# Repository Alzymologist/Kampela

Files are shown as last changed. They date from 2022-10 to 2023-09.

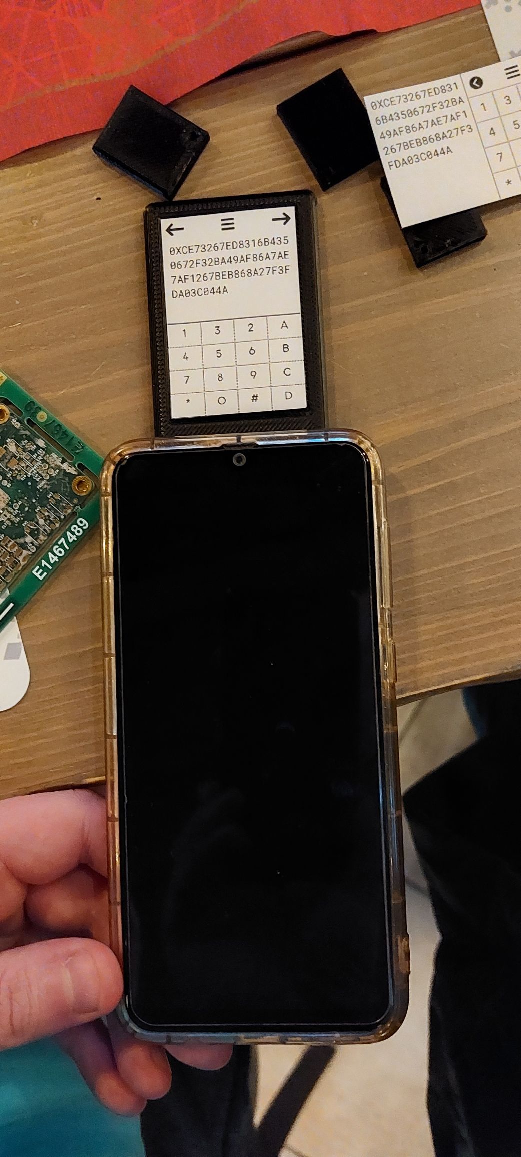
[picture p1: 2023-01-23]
hardware/development/Kampela_C1_enclosure/dummy/20230111_154535.jpg

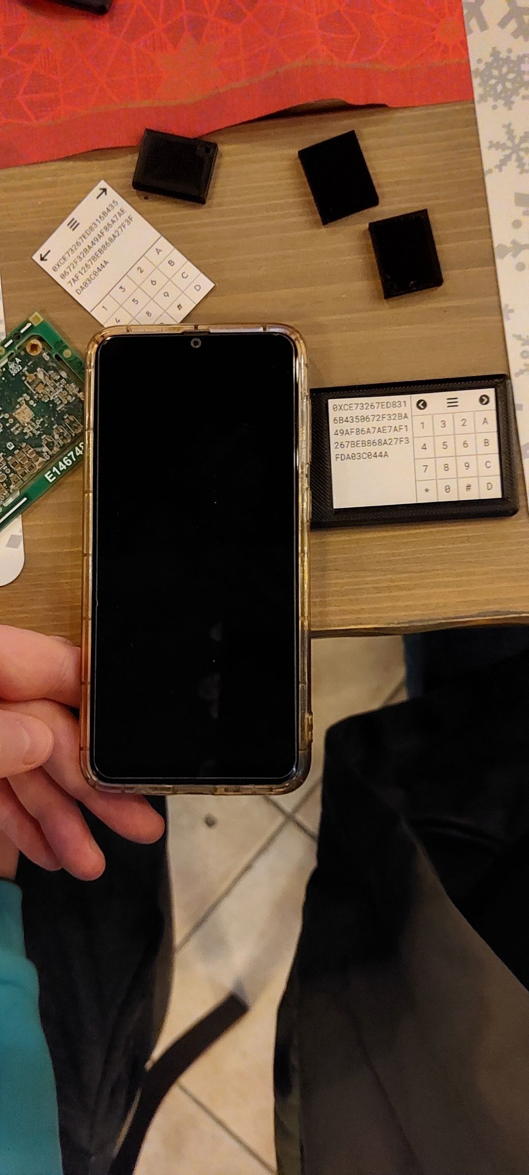
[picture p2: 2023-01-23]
hardware/development/Kampela_C1_enclosure/dummy/20230111_154515.jpg

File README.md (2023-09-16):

# Kampela
Hardware signer and key storage for Substrate ecosystem.
https://kampe.la

-------------------------------------------------
As of September 2023, this monorepo became really hard to work with, and had been splitted into multiple ones under the new [Kalapaja](https://github.com/Kalapaja) organisation.  
⚠️ This repo is kept up for archival reasons, please submit any issues and pull requests in that new org instead.

The new repository structure under Kalapaja is the following:

| New repository | Original subfolder | Description |
|---|---|---|
|[kampela-firmware](https://github.com/Kalapaja/kampela-firmware)|[`firmware/development`](https://github.com/Alzymologist/Kampela/tree/main/firmware/development)|Firmware sources and associated software projects|
|[kampela-hardware](https://github.com/Kalapaja/kampela-hardware)|['hardware/development'](https://github.com/Alzymologist/Kampela/tree/main/hardware/development)|Hardware design schematics and supplementary files|
|[kampela-common](https://github.com/Kalapaja/kampela-common)|['common'](https://github.com/Alzymologist/Kampela/tree/main/common)|Collection of shared libraries used by both "hot" and "cold" side of the project|
|[siltti](https://github.com/Kalapaja/siltti)|[application](https://github.com/Alzymologist/Kampela/tree/main/application)|Android companion app to interface with the device|
|[docs](https://github.com/Kalapaja/docs)|[docs/development](https://github.com/Alzymologist/Kampela/tree/main/docs/development)|Miscellaneous docs documenting different aspects of the project|

-------------------------------------------------

## Project summary
Kampela is a hardware version of Parity Signer. It is a small card-shaped device (ideally comparable to a credit card form factor, to be carried in a wallet when needed) that accepts data through unidirectional NFC port and shows output on a monochrome electronic paper screen. It has cryptographic strongbox with elliptic curves supported by Substrate —  which only stores private keys (after initial import) and performs all signing operations on-chip.

Kampela is designed to be a comparatively low-cost (below €100, in contrast to €500+ for a Signer-compatible smartphone) single-purpose device, which would only support a single seed phrase per unit, operated via a drastically simplified user interface. However, it would have all the security features of Parity Signer: a full-featured SURI account derivation system, transactions preview, metadata updates, logging.

As something that supports the same QR code output formats as Signer, it would be able to drop-in replace Signer when providing signatures back to a mobile/desktop wallet. The only challenge would be in transforming the current QR-driven input format of Signer into a suitable NFC payload. Alongside with native support in some apps (which would require software modification) this can also be achieved with a tiny “translator” app for a regular (online, not necessary trusted — one’s usual daily driver) mobile phone: it would snap a QR code with the transaction details and (statelessly, without any extra features or complicated UI) transform that into an NFC payload.

Kampela is a natural (and long-discussed) extension of Parity Signer to leverage the most out of modern hardware-based crypto chips and drastically reduce Signer’s attack surface: no mobile OS, not extra platform features, no unexpected communication methods or airplane mode to take care of.

Kampela is not a wallet! It is a signing tool, it is not able to track on-chain balances, validate things over chain-provided information or generate transactions on itself.

## Problem statement

Parity Signer project is a unique solution to provide user-friendly secure airgapped signing with seamless integration into ecosystem. However, there are certain problems that could not be solved at the moment:

Hardware cryptographic chips in modern phones do not support elliptic curve algorithms used in Substrate networks — so in result secrets being exposed to the main RAM of the device for the duration of usage (only hardware-encrypted at rest), where it may potentially leak or be accessed by malicious software.

Current hardware compatibility is limited: only newer iOS devices and few latest models of Android devices support hardware encryption of secrets. This puts supported devices on the more expensive side of the price range.

With iPod Touch being decommissioned, all devices currently in production which support necessary hardware features also include baseband chip — which runs a separate closed-source OS running on a separate, special-purpose chip while commonly having a full DMA access to the main phone’s memory. This chip could not be trusted (see Samsung’s baseband backdoor as an example) and has potential to leak secrets through radio channel or by use of kleptography, overriding on-board entropy generation or execution environment.

## Details

Kampela is an approximately credit card sized box with a rectangular screen and minimalistic controls (capacitive buttons alongside the screen or something similar — to be designed). In addition to development of the device itself (which will be available under suitable FOSS licenses both in terms of software and hardware designs), a reference MVP implementation of QR-to-NFC converter app will also be created.

After seed phrase initialization (either input or random generation — the latter being a potential technical challenge due to its computational/UX intensity and lack of entropy available) it will be stored in an hardware-backed encrypted storage. Address derivations could be created in Kampela either by passing derivation strings from mobile device via NFC (since those are not secret on their own) or by typing on the device itself (with some form of dictionary-driven assisted input, due to limited controls available); resulting public keys could be exported through QR codes, in the exactly the same way as with Parity Signer. Transactions for signing are sent into Kampela via NFC, their contents rendered on low-power e-ink monochrome screen and then user can unlock the device and sign transaction. Unidirectional nature and limited range/direction of both communication interfaces ensures that user remains in full control of data. Kampela has no battery (at least no battery for long-term power supply) and is powered only through NFC — which adds another layer of security, since no long-term backdoors can survive in RAM, and compromising the stored firmware itself is a much higher bar to clear for the attackers. Kampela will use a Secure Element or similar technology (like Arm TrustZone) to store secrets in a way, which will make it as hard as realistically possible to extract the secret keys, even with full physical access to the device and lab equipment being available.

Kampela is envisioned to be as close to open hardware criteria as possible, as long as it won’t compromise the resulting security model directly (for example, if requirement to support arbitrary user-provided firmware would clash with chosen security model, we would choose security model; all such cases would be clearly argumented and documented, of course). All security-sensitive parts of the device (NFC, RNG) would be implemented as much as possible through discrete, fixed-logic components (potentially with FPGA for the more uncommon parts of it, like sr25519  crypto) instead of being done “in software” or trusted to all-in-one integrated chip developers. Firmware for the programmable part of the device is to be written in Rust. On the smartphone companion app, it would use the same proven combination of Rust and native platform-dependent frameworks as Parity Signer currently does.

Unlike other projects in the similar problem space (which routinely withheld certain design specifications, and make others only available under an NDA, see, for example, discontinued project Cobo), we aim to make an extreme push to transparency of our designs, both on hardware and software layers. While this is expected to provide a boost in security and verifiability of Kampela devices, this severely restricts any potential future commercialization effort, since the competition (which wouldn't have to recover R&D costs) would undercut any official manufacturers on profit margins. We'd prefer this extreme competition to be a feature, not a bug; the only project with comparable manufacturing model would be Trezor, but it has a series of well-known shortcomings both in design and hardware choice areas.

## Ecosystem Fit

Currently, there are not too many options to securely handle keys in the Polkadot/Kusama ecosystem. There’s some Ledger support (which is often lagging behind the runtimes update cadence, and doesn’t exist for all the parachains out of the box), and Parity Signer and it’s fork Stylo (which requires an expensive smartphone device being used for this airgapped purpose only, and also has a much wider attack surface due to the device having a general-purpose OS and at least potential WiFi/3G/Bluetooth connectivity). We expect Kampela (having its own set of quite distinct tradeoffs) to supplement those two solutions — and integrate nicely with other layers of the tech stack (wallets, browser extensions etc), being a drop-in replacement of the currently already broadely supported Parity Signer.

## Origins of the name

Kampela, a flatfish — since the device is flat and is intended to resist phishing.

## Why Polkadot network?

Kampela project is a long-missing component to ultimately harden security of the whole Substrate ecosystem and ensure it’s secure and unstoppable status in long-term. Polkadot part of the greater ecosystem, as flagship and stable reference core, is natural space to develop universal solid solution like Kampela.

## Reviewers responses

Q: I think the NFC part isn’t very great from a usability perspective.

A: On contrary, NFC transfer of data into the device would be much smoother than with QR movies, especially for large payloads like metadata. The idea is that user will attach Kampela to the back of the smartphone, perform all the operations that do not require security with convenience of familiar smartphone interfaces, then flip the stack over and perform secure operations until output QR is shown. With QR presented on e-ink screen, Kampela could safely be detached from the phone as the QR intended for public broadcast would remain on screen. The task of mechanical engineer in this project (in addition to making device casing cheap to produce and robust) would be to ensure this flow is as comfortable and universal across the phones as possible.

Q: I guess the user does not really care about the RAM exposure as long as my phone is offline all the time.

A: Unfortunately, this is not so. The applications that could corrupt memory used by the signing application could manipulate RNG into leaking arbitrary data (including leaked secrets) through kleptography methods without exposing the leakage in any way. The leaked secrets could be broadcasted secretly through signature screen or other non-disabled communication methods via steganography. Finally, secrets leaked to memory could be stored outside of hardware encrypted storage negating its benefits in case attacker has physical access to the device reducing his need for fully-equipped forensic lab to relatively cheap and widespread memory dumping equipment. The Kampela solves these issues by lack of shared execution environment (and potentially rogue independent blackbox systems on board) and solid rust code with proper zeroization implemented.

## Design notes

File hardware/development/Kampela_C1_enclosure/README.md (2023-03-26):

## Mechanical design

The Kampela enclosure must meet many requirements:
1. Transparent design - the user must, among other things, visually understand that his Kampela has an original open-source design, manufactured at an authorized factory without any visible modifications.
2. Resistance to physical hacking and modification - access to the modification of electronics and flashing not factory firmware should be as difficult as possible.
3. Resistance to accidental breakage, abrasion, and display breaking - the basic requirements for carrying a device in your backpack
4. Fixation on the phone during use - the possibility of convenient simultaneous work of the user with a smartphone and with the Kampela touch screen both on hands and in a fixed position on the table.
5. Consisting of 2 parts - Kampela itself and an additional NFC key in the form of a keychain inserted into the middle part of the Kampela antenna.
6. Large touchscreen display to allow simultaneous viewing of keys and entry of verification codes on a randomized touch keyboard.

Based on the requirements and research results, we decided to manufacture the Kampela enclosure in the form of casting the board and display using Low-Pressure Molding technology into transparent amber polyimide.
This technology offers good opportunities for Kampela:
- Low-Pressure Molding, unlike two-component molding and injection molding, allows electronics to be technologically molded without damage from pressure or temperature.
- Polyimide is transparent, you can make sure that the copy of Kampela has the original design and corresponds to the open-source documentation.
- With the correct technology, polyimide is almost impossible to separate from the board without visible traces, thus hidden modification of electronics is excluded.
- The material, after curing, has a hardness of 80 Shore A. In combination with the semi-gloss surface texture, Kampela will adhere well to a smartphone. This will make it easy to work with Kampela when using both on the go and the table.
- Low-Pressure Molding allows you to make the device completely sealed and shock-absorbing when dropped, making Kampela resistant to accidental breakage.

## How to make your prototype Amber Kampela

For the Kampela prototype, we prepared 3D models so that any enthusiast can repeat Kampela and test usability.
Low-Pressure Molding equipment is not available to everyone, but the technology of two-component molding of polyurethane into silicone molds allows you to repeat the concept of Kampela molding in almost any workshop.
The algorithm for pouring two-component polyurethane is as follows:
0. You should have a Kampela board assembled, sewn, and fully tested, a set of transparent molded silicone with a silicone mold hardener, a kit of molded two-component polyurethane for molding (amber, 80 Shore A), corrugated cardboard for mold walls, hot glue gun for sealing joints when pouring silicone, release wax spray, sharp scalpel for parting a mold, SLA 3D printer for printing a master model for pouring, dirty room or polyethylene-covered floor and workplace (be careful! Two-component casting components are very difficult to remove from furniture, floors, and clothes, so it’s better to immediately tighten everything with disposable plastic wrap)
1. Print the master model on the SLA 3D printer using the STL file from the GitHub repository
2. Make a silicone mold box out of cardboard by adding a minimum of 3cm on each side of the master model. Be sure to seal the joint between the bottom and the walls of the box with a heat gun for pouring, otherwise, the silicone will leak into the joint, as it is very fluid.
3. Glue the master model to the bottom of the box with the Kampela screen facing up using thin double-sided tape so that it does not float when poured.
4. Spray the wax release agent onto the master model from above.
5. Mix and pour the casting silicone according to the instructions on it up to half the box, but so that the master model is completely covered with silicone. Wait for the silicone to cure
6. After curing, remove the pot from the box, turn it over and insert it into the box with the visible master pattern facing up. Do not remove the master model. Glue 2 wooden sticks or tubes from soda with a diameter of 4-6 mm to the master model on both sides of the mold to then pour polyurethane through them - one for pouring, the second for the air outlet. Spray the wax separator over the top. Fill the second half of the mold with silicone. Wait for confirmation.
7. After the mold has cured, you can split the mold, remove the master model, clean the mold with a brush or compressor from dirt and start casting polyurethane.
8. To fill the mold with polyurethane, assemble the injection mold: place the assembled Kampela board with the display, and position it on the buttons and silicone ledges in the master model. Close the mold and fasten sheets of hard cardboard at the top and bottom and fasten the mold with rubber bands so that it is tightly assembled, but the sprues are accessible for pouring with a syringe.
9. Mix polyurethane according to the instructions for it, and degas according to the instructions. Then, with a large disposable syringe of suitable capacity, without a needle, suck the polyurethane from the mixing container and pump it into the silicone mold until enough polyurethane comes out of the air hole. Make sure that the form lies on a plane horizontally so that the polyurethane does not flow out and there is no possibility of the formation of bubbles in the voids of the form that will be above the air outlet channel.
10. Once the polyurethane has cured, you can use your sealed and shockproof Kampela.

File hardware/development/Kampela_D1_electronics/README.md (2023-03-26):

# D1 iteration electronics design progress:

## Display and touchscreen

For ease of use with the device, this iteration used a 2.7" e-inc touchscreen display. We also examined e-inc displays of other diagonals in terms of usability and usability in the Kampela layout, as well as displays powered by memory technology displays. Alternative display manufacturers with the same parameters were also found to ensure supply reliability.

Displays based on memory display technology look very promising - the refresh rate compared to e-inc allows for a more responsive touch interface. The problem lies in the small number of manufacturers of suitable displays found and the lack of available touch screens for such displays. Security aspects of using this technology should also be carefully analyzed, as sensitive key material does indeed pass through memory display’s memory cells, which have some limited non-volatility. Yet in the future iterations, we want to work more with memory display and try to implement a fast, responsive touch interface, possibly with color.

## Separate layout of the coil and main board

In this iteration, the NFC coil has been separated from the main board. This was done based on the following tasks:

1. When placing the board with the display and the coil in the case, taking into account the thickness of the display, the protection of the display, and the case, it turns out that the coil moves away from the phone at a distance of more than 3mm, which negatively affects the efficiency of wireless power transmission and the overall power reserve in Kampela. The division of the coil and the main board into 2 boards in this case allows you to place the coil in the case as close as possible to the plane of the smartphone while using the device remains just as convenient.

2. The separate layout of the coil and the main board allows you to experiment with different coils in the package without changing the main board. In the next iteration, we will be able to choose the optimal coil option in this way.

## Self-destruct mechanism

In latest iteration, device self-destruct chains were added, activated by the user either by physically damaging the screen or other area of casing and then exposing Kampela to NFC field; we would experiment to determine most reliable and convenient method in the next milestones. Self-destruct indication circuits have also been added so that the user can visually check that the device cannot be used for its intended purpose after self-destruction: instead of RED power overload LED, a BLUE LED indicating successful processor wipe would be illuminated.

## Separation of display and touch screen resets

In the first prototype, lots of cross-talk was found between display and touch panel circuits: power dip on screen refresh occasionally triggers touch touch events, i2c line gets locked, etc. Thus the RESET circuits of the display and the touch screen were separated due to mutual influence during operation. The power circuits of the display and the touch screen were also separated and optimized to avoid their negative influence on each other. Furthermore, this would improve power management of Kampela, as with this separation touch panel could be disabled during screen update, significantly reducing power drain and subsequently brown-out probability during normal operation.

## Improvements to component patterns and board layout

In this iteration, the documentation for the display, touchscreen, cables, and other components has been clarified, and the component patterns have been corrected and optimized. The layout of the board has also been optimized so that the cables take a mechanically unstressed position, and the mounting of components on the board has also been optimized.

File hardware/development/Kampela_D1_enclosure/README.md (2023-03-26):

# D1 iteration mechanical design progress:

## Aluminum body frame

In the process of working on the flooded version of Kampela, the lack of strength of the flooded device was revealed - both in terms of the integrity of the board and in terms of the integrity of the display. Also, in the process of working on the molding of the board with the display, problems with stable and accurate positioning of the display during molding were identified. To avoid these problems, it was decided to add a rigid frame to the layout, which would increase the rigidity of the structure and would allow the elements to be reliably positioned when pouring the compound. Aluminum was chosen as the frame material for the time being, and non-conductive, lighter and more corrosion-resistant plastic materials are considered in future. The influence of metal on the efficiency of wireless power transmission was experimentally investigated and measures were taken to increase efficiency - slots were added to avoid closed turns.

## Active NFC dummy tag inlay

As an additional authentication factor, as well as for direct communication between the NFC smartphone and Kampela, we use an NFC memory chip with an independent antenna. It was decided to implement this scheme in the form of a hermetic key fob detachable from the main device, without which Kampela does not allow to perform its functions. The key fob is implemented in the form of a small printed circuit board poured into a transparent compound and placed inside the main Kampela coil. Structurally, the key fob is implemented in such a way that it does not fall out of the case when using Kampela directly with a smartphone, but if necessary, it is possible to remove it from the Kampela case for inspection that the circuits are indeed indepentent, and, if we manage to implement proper strong signing in active tag, use the fob as second authorization factor. At the moment, the most optimal design of the tag was chosen with a transparent plastic base, a printed circuit board of the tag embedded in it, and the subsequent hermetic filling of the tag.

## Filling and sealing

Experiments with sealed PCB potting showed good technology potential for the device, but also revealed several technical problems:

- When pouring, accurate and reliable positioning of the display and printed circuit boards are required, otherwise, they may "float" in the volume of the poured compound and change their final position.

- Some fill elements are very thin, such as the protective damper around the display and the area around the display and touch screen flex cables. The small thickness makes it difficult to pour without bubbles and cavities at low filling pressures. The use of high pressures for filling electronics and e-inc displays is not possible

- Flexible cables of the display and touch-screen require fixing before pouring in order not to go to the pouring surface and form air pockets.

Based on these issues, it was decided to use a rigid aluminum frame to solve these problems, and to perform a hermetic filling from the back of the device. At the same time, the device remains transparent and sealed and does not allow hidden modifications. In the next milestones, we will work on optimizing the layout and design of Kampela to make it more technologically advanced and more user-friendly.

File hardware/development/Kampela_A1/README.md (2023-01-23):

# CoilDisp

This devboard uses `STN32L432KCU` mc to test power harvesting to power a e-ink screen.

## Power harvest

The board supports connection of printed coil or external coil. Additionally, a UFL connector for VNA for coil model parameters analysis is implemented

## Power storage

The power is stored in smd ceramic capacitors; external connections for electrolytic capacitors to support londer unpowered states and balance high poewr consumption during screen refresh cycle are implemented

## Screen

The component for testing is PervasiveDisplays model E2154CS0C1

[Datasheet](https://www.pervasivedisplays.com/wp-content/uploads/2021/12/1P255-00_03_E2154CS0C1_202111203doc.pdf) and [programming guide](https://docs.pervasivedisplays.com/epd-usage/epd-driving-sequence/small-epds) are available at PervasiveDisplays website.

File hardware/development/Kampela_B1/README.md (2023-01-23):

# Kampela conveptual testing module

This PCB tests several important concepts that would be used in actual Kampela device.

## Signal forming circuit

Filter stage is added on data input channel to intercept smartphone data and active NFC tag responses.

## Touchpad

Connector for touchpad is added to this board.

## Overdrive indicator

Excess power is dissipated through a clamp with LED. Brightly shining this LED effectively indicates that signal power is more than enough and could be used for Kampela alignment.

## RAM

RAM chip is added to the board to check its performance with our power system.

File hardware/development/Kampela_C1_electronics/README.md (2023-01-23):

# Kampela integration prototype

This is the design for the first version of complete Kampela device.

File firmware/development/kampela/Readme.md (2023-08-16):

# Requirements
We assume that you have linux.

Set of packages as well as commands could vary depending on your distribution.
Following is valid for ArchLinux.

Install rustup and ARM toolchain:
```sh
[sudo] pacman -S rustup arm-none-eabi-gcc arm-none-eabi-binutils
rustup update
rustup default stable
```

Also you will need a program for flashing.

For Pilkki flasher look [here](https://github.com/Alzymologist/pilkki).

For Segger you need to install [simplicity-commander](https://www.silabs.com/developers/mcu-programming-options).
In case of ArchLinux there is [AUR package](https://aur.archlinux.org/packages/simplicity-commander).

# Preparations

```sh
rustup target add thumbv8m.main-none-eabihf
cargo install flip-link
```

# Build

```sh
cargo build --release
```

## Flashing

In case of Pilkki:
```sh
./binarize.sh --pilkki
```

And in case of Segger
```sh
./binarize.sh --segger
```

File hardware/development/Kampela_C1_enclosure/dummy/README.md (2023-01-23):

# Casing design development

This folder contains casing design dummies information. These were intended to be 3-d printed to get a feel of Kampela in use with typical smatrphones.

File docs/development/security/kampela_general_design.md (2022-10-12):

# Kampela screens

Kampela has two screens:

- QR screen (for QR exports and signatures)

- Display screen (for other data: derivations list, specs available, verifiers etc)

All output from Kampela must be through either of these screens.

# Kampela gets commands only through interface

By receiving appropriate NFC from introduced device, Kampela can:

- load chain specs (save specs in storage)
- create an address (save public address information in storage, create export QR on Qr screen.)
- sign a transaction
- sign a text message
- remove chain specs
- remove an address
- show info in Kampela (nothing is sent, Kampela own controls are used)

NFCs from alien devices are not accepted. Introducing device requires pin code.
Any action on Kampela requires on-Kampela user confirmation (i.e. user reading from Kampela screen the incoming transaction) and a pin entry.

# Kampela is as expected

There must be a set of checks for Kampela in place.

1. Code/design are audited, well, at least looked into, as any open source.
2. Factory receives chips as designed.
3. Assembly in factory is as designed.
4. Firmware in factory is as designed.
5. Assembly/hardware remains the same while in transit to user.
6. Firmware same remains the same while in transit to user.
7. Assembly/hardware can not be swapped quickly and discreetly while Kampela is with user.
8. Firmware can not be swapped quickly and discreetly while Kampela is with user.

# Summary of secret-related storage in Kampela.

1. Part of chip own secret key, as set in chip factory.
2. Part of chip own secret key, added in Kampela assembly factory.
As the Kampela exits the Kampela assembly factory, the chip secret key is complete, and factory records the Kampela public key.
User checks that the chip is genuine by signing a challenge with chip secret key and verifying with public key known at Kampela factory.
3. Firmware build is stable. Its hash must match the officially published one. Hash is checked, ledger-like protocol here.
4. User own secret (seed phrase, secret key?) - entered by user, stored encrypted with chip-intrinsic PUF-containing key (same as 2 or separate?).
5. Pin code - for unlocking the Kampela; possibly mix into user secret encrypting key (4).
6. Companion phone(s) public key(s).

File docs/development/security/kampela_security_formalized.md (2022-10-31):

Kampela protects only user secrets, user assets, and user identity.
This text deals only with the effects of various attacks on user.
Attacks are ranged by proximity of the potential attacker to Kampela device.

Integrity breaches are considered entirely unacceptable. Base incentive: High.
Confidentiality breaches are highly undesirable. Base incentive: Medium.
Availability breaches could be tolerated. Base incentive: Low.

Note: availability failures might be used as basis for blackmailing attack though, where, even though the secrets are safe (considering that user did indeed follow backup protocol), financial damage could occur. Think big brute holding your device and demanding a dollar to give it back; for a small enough sum, this transaction might happen regardless of whether Kampela is still operational or even actually returned upon payment. This is not very different from similar attacks elsewhere and would not be considered here much, as only user's wits could protect from these.

There is one special case, where the user is tricked into using account with derivation path known only to attacker; here the legal user and an attacker share components to unlocking the account and would have to negotiate. Here, though, the secret is actually compromized in one signature or public key generation event; thus technically this is an integrity breach (much like signing a single malicious proxy call to delegate full control to attacker). Attacks where public key is substituted outside of Kampela are out of scope here.

# 1 Kampela in direct access, for unlimited period of time (stolen, found, etc)

Note 1. If an attacker knows the pin code, the game is over, it is the same as if the attacker has the secret phrase. We will assume that the attacker does not have the pin.

Note 2. User must follow end-of-life disposal protocol, otherwise normal use will end up here.

Base effort: Medium

## Confidentiality

Motivation: Stalk or expose the user.

1-C1

Attacker action: Get all public keys, including the ones the user hides from wide public, stalk user through polkascan.

Effort: Medium

Incentive: Medium

## Integrity

Motivation: Get access to user identities and assets.

1-I1

Attacker action: Read secret phrase. Attacker must break through authentification.

Effort: High

Incentive: High

1-I2

Attacker action: Carefully disassemble the device, read secret with advanced instrumentation.

Effort: High

Incentive: High

1-I3

Attacker action: Proxy account control. Attacker must break through authentification.

Effort: High

Incentive: High

1-I4

Attacker action: Attacker takes the device after it is unlocked by user.

Effort: High

Incentive: High

## Availability

Note. If user loses whether the detachable token, or Kampela, or both, the availability is inevitably lost.

# 2 Kampela in direct access, briefly (stolen and returned, device remains the same)

Note. If attacker knows the pin code, the game is over, attacker same as has the secret phrase. Assume here they don't have the pin.

Base effort: Medium

## Confidentiality

2-C1

Same as direct access for unlimited period of time.

## Integrity

2-I1

Motivation: Get the secret phrase.

Attacker action: Break pincode by observing physical state of the Kampela (scratched buttons, etc).

Effort: High

Incentive: High

2-I2

Motivation: Swap chain specs so that later transactions are parsed incorrectly and signed without knowing true content.

Attacker action: Send chain specs NFC payload, accept it.

Effort: High

Incentive: Medium

2-I3

Motivation: Swap chain verifier so that later compromised metadata is fed to Kampela, thus transactions are parsed incorrectly and signed without knowing true content.

Attacker action: Send chain specs NFC payload with new verifier, accept it.

Effort: High

Incentive: Medium

2-I4

Motivation: Seed phrase swap.

Attacker action: Change seed phrase, user generates wrong public key in companion and uses it to accept assets. Attacker must break through authentification.

Effort: High

Incentive: High

2-I5

Motivation: Seed phrase swap.

Attacker action: Coerce user to remove secret. Enter wrong secret (by taking Kampela shortly). User then generates wrong public key in companion and uses it to accept assets.

Effort: High

Incentive: High

2-I6

Motivation: Maliciously re-programm Kampela.

Attacker action: Kampela is shortly taken from user, re-programmed (for example, to compromize the secret through defective randomness), returned to user.

Effort: High

Incentive: High

## Availability

2-A1

Motivation: Destroy or block device.

Attacker action: Physically break device or enter wrong pin multiple times.

Effort: Medium

Incentive: Low

2-A2

Motivation: Temporarily stagger user activity.

Attacker action: Delete or damage seed.

Effort: Medium

Incentive: Low

2-A3

Motivation: Temporarily stagger user activity.

Attacker action: Remove one or more user addresses manually.

Effort: Medium

Incentive: Low

2-A4

Motivation: Temporarily stagger user activity.

Attacker action: Remove one or more chain specs manually.

Effort: Medium

Incentive: Low

2-A5

Motivation: Block user assets.

Attacker action: Copy derivation path, remove address manually, if user does not have backup, assets on address are blocked.

Effort: Medium

Incentive: Medium

# 3 Kampela in close proximity (watched over shoulder)

Base effort: Low

## Confidentiality

3-C1

Motivation: Peek at user's transaction.

Attacker action: Look over the shoulder or tap NFC field, it would probably be visible on other devices as well.

Effort: Low

Incentive: Low

3-C2

Motivation: Learn user's public key.

Attacker action: Look over the shoulder, it will be shown on other devices as well.

Effort: Low

Incentive: Low

## Integrity

3-I1

Motivation: Observe pin code or password.

Attacker action: Look over the shoulder, listen to button sounds.

Effort: Medium

Incentive: High (requires access to device later)

3-I2

Motivation: Make user sign malicious transaction.

Attacker action: Send transaction through powerful enough NFT transponder (and hope that user does not read it attentively).

Effort: High

Incentive: High

3-I3

Motivation: Swap chain specs so that later transactions are parsed incorrectly and signed without knowing true content.

Attacker action: Send corrupt chain specs with powerful transponder, make user accept them.

Effort: High

Incentive: Medium

3-I4

Motivation: Get information (possibly secret one) from device.

Attacker action: Listen to electromagnetic noise from device.

Effort: High

Incentive: High

Note. Research needed. Emissions should be minimal.

## Availability

3-A1

Motivation: Break device from a distance

Attacker action: EMP.

Effort: Medium

Incentive: Low

Note. Breaking may be unintentional, for example, burning circuits with too high signal (supermarket anti-theft etc).

# 4 Kampela far away (attacks without breaking the companion app)

Base effort: None

## Confidentiality

## Integrity

4-I1

Motivation: Trick user into signing proxy account.

Attacker action: Send proxy call, use social engineering.

Effort: High

Incentive: High

4-I2

Motivation: Trick user into switching to malicious verifier.

Attacker action: Use social engineering to make user change verifier.

Effort: Medium

Incentive: Medium

4-I3

Motivation: Distribute malicious chain data.

Attacker action: Steal verifier key or be malicious verifier.

Effort: High

Incentive: High (could be scaled to many users)

4-I4

Motivation: Trick user into signing transaction blindly.

Attacker action: Use social engineering.

Effort: High

Incentive: High

4-I5

Motivation: Use message signing to make signature usable elsewhere.

Attacker action: Find vulnerability where "sign message" mechanism has insufficient replay protection or message that collides with call, make user sign it.

Effort: High

Incentive: Medium

4-I6

Motivation: Compromise device firmware during an update, expose data and assets.

Attacker action: Publish/propose Kampela update that would install damaged/incorrect firmware into Kampela. User may sign transactions they did not agree to, or create addresses they did not wish to. Attacks may occur only if certain conditions are met, and thus be difficult to detect.

Effort: High

Incentive: High

4-I7

Motivation: Make user sign a wrong message.

Attacker action: Compose "sign_message" content with utf-8 symbols that are not printable and/or are metasymbols (reverse text direction, move caret, etc.), so user reads and signs different messages.

Effort: Medium

Incentive: Low

4-I8

Motivation: discover user pin code (device is later stolen to use the pincode and retrieve the secret).

Attacker action: Kampela, when used, is close to the companion device, maybe attached, definitely in visible proximity. Compromized companion device may record pictures of user entering pin code, analyze sensor data or button sounds to deduce what buttons user is pressing when entering the pin code.

Effort: Medium

Incentive: High

## Availability

4-A1

Motivation: Trick user to break device.

Attacker action: Convince user that blocking actions should be performed (self-destruct mechanism, verifier recall, EMP).

Effort: Low

Incentive: Low

# 5 Swap used Kampela (original device is replaced after secret entering)

Base effort: Medium

This includes only attacks through swap itself. Attacks through taken Kampela are discussed above, in 1-2.

User may not notice that the secret is missing (if the device does not show initiation screen) or that the secret is changed.
User most likely will not notice that the pin is not checked (but asked).

Swapped device contains a different secret or no secret at all. Swapped device may be a different Kampela or Kampela-like fake device.

## Confidentiality

5-C1

Motivation: Plant a tracking device (mic, gps tracker).

Attacker action: Plant fake Kampela-looking device with a tracker. No need to retrieve the original device here.

Effort: Medium

Incentive: Medium

## Integrity

5-I1

Motivation: Steal or expose the secret by making user re-enter the secret in Kampela replica.

Attacker action: Plant fake Kampela and compel user to re-enter the secret. Any damaging modification to Kampela (see 7-I1..7-I5) is applicable here. Original device may or may not be retrieved.

Effort: High

Incentive: High

5-I2

Motivation: Steal pincode by planting Kampela replica with retranslator.

Attacker action: Steal original Kampela and replace it with replica that demands pincode (as in any normal Kampela operation) and retranslates it somehow to the attacker. With original Kampela and pincode, the attacker has full access to the secret.

Effort: High

Incentive: High

5-I3

Motivation: Make user generate an address user has no or hindered access to. Attacker *has* access to the address, catches the funds transferred into the address.

Attacker action: Plant fake Kampela with a different secret inside. User creates address and sends funds to it, attacker can get or transfer funds before user notices the error.

Effort: Medium

Incentive: High

## Availability

5-A1

Motivation: Make user generate an address neither user nor attacker have full access to, demand ransom.

Attacker action: Plant fake Kampela with a different secret inside. User creates complex address with unexpected derivation and/or password, and sends funds to it, attacker demands ransom.

Effort: Medium

Incentive: High

# 6 Companion device compromised

Base effort: Low

An important note here is that a relatively simple way to perform this would be to swap the companion device. Thus, we should rely on companion device's authentication mechanisms and probably Kampela's ability to authenticate companion device and notify the user.

## Confidentiality

6-C1

Motivation: Learn key ownership information through complimentary app breaches.

Attacker action: Gain control over complimentary app and download log or set of keys.

Effort: Low

Incentive: Low

## Integrity

6-I1

Motivation: Trick user to export account with derivation path known only to attacker and then send assets there; blackmail to "reveal the secret"

Attacker action: Send a derivation with non-visualizeable symbols into Kampela through corrupted companion app; trick user into removing this derivation after some use. Alternatively: manipulate companion app to put the derivation different from the one the user intended. User creates account, does not notice the derivation difference, sends funds to account and can not get access to funds because no derivation.

Effort: Medium

Incentive: High

6-I2

Motivation: Make user sign transaction by wrong address (same seed, different derivation).

Attacker action: change public key in transaction to a different, corresponding to different derivation.

Effort: Medium

Incentive: Medium

6-I3

Motivation: Make user sign transaction different from one they were forming.

Attacker action: change transaction core in transaction to a different one.

Effort: Medium

Incentive: High

6-I4

Motivation: Steal user secret when it is loaded from shards (SSS protocol).

Attacker action: compromised phone camera sends all images to attacker. Each shard scan contains also the recovery phrase, thus the attacker would have all the data needed.

Effort: Low

Incentive: High

## Availability

6-A1

Motivation: Disable the Kampela

Attacker action: Try to engage self-destruct mechanism, scramble derivations tree or physically damage the tool

Effort: High

Incentive: Low

# 7 Swap unused Kampela (user gets fake device before secret entering)

Base effort: High

User gets malicious Kampela-like device instead of the real Kampela. Swap happens in factory, during the shipping, etc.

## Confidentiality

## Integrity

7-I1

Motivation: Steal secret through radio channel.

Attacker action: Make device replica with radio transmitter.

Effort: High

Incentive: High

7-I2

Motivation: Expose secret through kleptography.

Attacker action: Manipulate RNG in factory.

Effort: High

Incentive: High

7-I3

Motivation: Expose secret through kleptography.

Attacker action: Manipulate Kampela crypto libraries.

Effort: High

Incentive: High

7-I4

Motivation: Fog user operations (address generation, transaction signing) by malicious Kampela firmware.

Attacker action: Install damaged/incorrect firmware into Kampela. User may sign transactions they did not agree to, or create addresses they did not wish to. Attacks may occur only if certain conditions are met, and thus be difficult to detect.

Effort: High

Incentive: High

7-I5

Motivation: Steal secret stored in damaged device.

Attacker action: Modify Kampela to disable protection, get the user to use it, and then steal Kampela. Seems possible only if the identity of the user is known to begin with.

Effort: High

Incentive: High

## Availability

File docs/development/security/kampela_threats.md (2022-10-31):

<h2>Effort vs incentive, summarized</h2>

<table>
  <tr>
    <th></th>
    <th>Effort: Low</th>
    <th>Effort: Medium</th>
    <th>Effort: High</th>
  </tr>
  <tr id="first">
    <th  rowspan="20">Incentive: High</th>
    <td>6-I4 Steal camera data and get all information needed to recover user secret from the
      <br>shards (SSS) - QRs and secret phrase (usually written on the same paper)
      <br>Counter:
      <br>(1) user instructions: do not flash the secret phrase into the camera
    </td>
    <td>3-I1 Observe pin entering, use pin later.
      <br>Counter:
      <br>(1) user instructions
      <br>(2) touch screen buttons with shuffling
      <br>(3) optional: demand the second factor present for every pin entering
    </td>
    <td>1-I1/2-I1 Read secret from storage by breaking the pin.
      <br>Counter:
      <br>(1) pin must be difficut to break, guess or steal (trust user here?)
      <br>(2) allow limited (how severely?) number of attempts
      <br>(3) user responsibly creates, stores and safely uses the pin
      <br>Who, when and how sets the pin? User, right before setting up the secret.
      <br>Changing or resetting the secret allows to change the pin if not yet frozen.
    </td>
  </tr>
  <tr>
    <td  rowspan="19"></td>
    <td>4-I8 Get pincode via images/sensor data/sounds transferred to the attacker by
      <br>a compromized companion device.
      <br>Counter:
      <br>(1) shuffle sensor buttons to make any data except the visual one useless
      <br>(2) comfortable and recommended configuration keeps the screen with the
      <br>sensitive data off camera
    </td>
    <td>1-I2 Disassemble device, read secret instrumentally.
      <br>Counter:
      <br>(1) using PUF, breaking crypto chip would damage the secret
      <br>(2) trustworthy crypto chip
    </td>
  </tr>
  <tr>
    <td>5-I3 User creates address in planted Kampela with unknown secret, attacker gets funds.
      <br>Counter:
      <br>(1) personalized Kampela
    </td>
    <td>1-I3 Proxy address by breaking the pin.
      <br>Counter: same as 1-I1/2-I1
    </td>
  </tr>
  <tr>
    <td>5-A1 User creates address in planted Kampela with unknown secret, attacker demands ransom.
      <br>Counter:
      <br>(1) personalized Kampela
    </td>
    <td>1-I4 Take device already unlocked by user.
      <br>Counter:
      <br>(1) Kampela is active for a very short time after disconnect with companion device,
      <br>can add the switch that powers down the device if the field is lost.
      <br>(2) demand pin second time when accessing secret
      <br>(3) demand pin when adding data or signing transaction
      <br>This still leaves uncovered removal/swap of the specs and derivation. So:
      <br>(4) allow device to receive any payloads only from the introduced companion devices
    </td>
  </tr>
  <tr>
    <td>6-I1 Manipulate companion into making derivation with unreadable symbols in path and/or unknown to user, ransom.
      <br>Counter:
      <br>(1) make Kampela store all created derivations
      <br>(2) additionally display derivation path as set of hex characters from Kampela
    </td>
    <td>2-I4 Swap secret unbeknownst to user, catch funds on account unrelated to user.
      <br>Counter:
      <br>(1) user is encouraged to freeze the secret (reminders, instructions)
      <br>(2) once the secret is frozen, it could not be changed
    </td>
  </tr>
  <tr>
    <td>6-I3 Manipulate companion into swapping the transaction content.
      <br>Counter:
      <br>(1) parse transaction on Kampela and display it to user, so that user signs definitely what was parsed
      <br>(2) forbid blind signing
    </td>
    <td>2-I5 Coerce user to "fix" the secret, manipulate secret on entering, catch funds on account unrelated to user.
      <br>Counter: same as 2-I4
      <br>Here we can only make Kampela somewhat uncomfortable to use when the secret is not frozen.
    </td>
  </tr>
  <tr>
    <td  rowspan="14"></td>
    <td>2-I6 Maliciously re-programm Kampela.
      <br>Counter:
      <br>(1) any changes in code can be loaded only if Kampela is opened up
      <br>(2) Kampela body must be tamper-evident
    </td>
  </tr>
  <tr>
    <td>3-I2 Make user sign a malicious transaction (sent with powerful transponder).
      <br>Counter:
      <br>(1) parse transaction on Kampela and display it to user, so that user signs definitely what was parsed
      <br>(2) forbid blind signing
      <br>(3) Kampela can receive data only from the introduced companion devices
    </td>
  </tr>
  <tr>
    <td>3-I4 Listen to device.
      <br>Research needed here. Noise from Kampela's inner circuit is expected to be minimal, but that must be checked.
    </td>
  </tr>
  <tr>
    <td>4-I1 Make user sign proxy (social).
      <br>Counter:
      <br>(1) Kampela parses and shows the action of signing off account as a proxy.
      <br>Not much Kampela itself can do against social manipulation.
    </td>
  </tr>
  <tr>
    <td>4-I3 Distribute malicious chain data.
      <br>Counter:
      <br>(1) metadata is transferred to Kampela together with signature; signature is checked on Kampela and must
      <br>correspond to the verifier already known to Kampela
      <br>(2) user is encouraged to trust only reliable verifiers
      <br>(3) user is encouraged to have as few verifiers total as possible to manage verifier info easily
      <br>(4) malicious verifier, if public and broadcasting, can be pointed out by community
      <br>(5) if the chain data used for transaction generation goes on chain, this becomes entirely obsolete
    </td>
  </tr>
  <tr>
    <td>4-I4 Make user sign transaction blindly (social).
      <br> Counter:
      <br>(1) forbid blind signing
    </td>
  </tr>
  <tr>
    <td>4-I6 Install damaged firmware on Kampela during the update.
      <br> Counter:
      <br>(1) block updates except in Kampela "hacker edition" (that is not expected to be used for real secrets)
    </td>
  </tr>
  <tr>
    <td>5-I1 Plant malicious Kampela replica instead of used Kampela, make user re-enter the secret, steal or expose or misuse it.
      <br> Counter:
      <br>(1) user instructions - secret re-entry must be highly suspicious
      <br>(2) personalize Kampela
      <br>(3) introduce Kampela to the companion device, so that the companion device also would
      <br> have to be swapped in this case or will notify user of the Kampela swap
    </td>
  </tr>
  <tr>
    <td>5-I2 Plant malicious Kampela that demands pin and retranslates it, steal the original Kampela, get both the Kampela and the pin.
      <br> Counter:
      <br>(1) personalize Kampela
      <br>(2) introduce Kampela to the companion device, so that the companion device also would
      <br> have to be swapped in this case or will notify user of the Kampela swap (flimsy,
      <br> because responsive part is removeable from Kampela, Kampela itself is silent)
    </td>
  </tr>
  <tr>
    <td>7-I1 Replica with retranslator to steal the secret.
      <br> Counter (to demonstrate that the chip is genuine):
      <br>(1) checkable genuine chip:
      <br>Kampela must be able to sign a verification challenge with its internal secret.
      <br>Internal secret is intrinsic to a device and factory known only a public key from it.
      <br>Maybe part of the internal is from chip itself and part is from Kampela assembly,
      <br>so that the entire secret is not known unless the two cooperate to know it.
      <br>(2) visibly intact casing
      <br>(3) QA and traceability if manufacturer goes rogue
    </td>
  </tr>
  <tr>
    <td>7-I2 Replica with damaged RNG.
      <br>Counter:
      <br>(1) checkable genuine chip, see 7-I1
    </td>
  </tr>
  <tr>
    <td>7-I3 Replica with damaged crypto libraries.
      <br>Counter:
      <br>(1) sign reproducible builds, check signature on-board, etc.
    </td>
  </tr>
  <tr>
    <td>7-I4 Replica with malicious firmware.
      <br>Counter:
      <br>(1) use stable build, check build signature
    </td>
  </tr>
  <tr>
    <td>7-I5 Steal secret stored in damaged device.
      <br>Counter:
      <br>(1) verify chip authenticity
    </td>
  </tr>
  <tr id="first">
    <th  rowspan="5">Incentive: Medium</th>
    <td  rowspan="5"></td>
    <td>1-C1 and 2-C1 Stalk user after discovering all public keys.
      <br>Counter:
      <br>(1) pin is needed to unlock the Kampela
      <br>(2) user is encouraged to delete Super Secret Derivations and keep them backed up elsewhere
    </td>
    <td>2-I2 Swap specs (steal Kampela).
      <br>Counter:
      <br>(1) any new device can be introduced only with the pincode, even on unlocked device
    </td>
  </tr>
  <tr>
    <td>2-A5 Copy path from Kampela, delete address, demand ransom to restore.
      <br>Counter:
      <br>(1) user is encouraged to keep backups in some form
    </td>
    <td>2-I3 Swap verifier.
      <br>Counter:
      <br>(1) user is expected to check the verifier public key when loading updates
      <br>(2) payload with verifier change is expected to come from known device,
      <br>introducing a new device is pin-protected
    </td>
  </tr>
  <tr>
    <td>4-I2 Malicious verifier (social).
      <br>Counter:
      <br>(1) community reputation?
    </td>
    <td>3-I3 Swap specs (transponder).
      <br>Counter:
      <br>(1) payloads can be accepted only from a known companion device
    </td>
  </tr>
  <tr>
    <td>5-C1 Plant replica Kampela with a tracking device.
      <br>Counter:
      <br>(1) personalized Kampela
    </td>
    <td>4-I5 Bytes and collision.
      <br>Counter:
      <br>(1) display message and hexadecimal payload to protect from outrageously
      <br> suspicious messages (possibly with undisplayable symbols highlighted)
      <br>(2) hope that at some point upstream will implement context for signing
      <br>But really this boils down to too much effort for questionable profit.
    </td>
  </tr>
  <tr>
    <td>6-I2 Sign with wrong public key (wrong derivation).
      <br>Counter:
      <br>(1) Kampela displays and user is expected to check the signing address
    </td>
    <td></td>
  </tr>
  <tr id="first">
    <th  rowspan="6">Incentive: Low</th>
    <td>3-C1 Observe user transaction.
      <br>Transactions are on chain anyways, only trouble is association of address with user.
      <br>See 1-C1/2-C1.
    </td>
    <td>2-A1 Destroy or block Kampela.
      <br>Counter:
      <br>(1) back up secrets and derivations safely
      <br>(2) make Kampela sufficiently cheap to be replaceable
    </td>
    <td>6-A1 Engage through companion self-destruction, derivations damage or tool damage.
      <br>Counter:
      <br>(1) initiate self-destruction from Kampela? no api for remote?
    </td>
  </tr>
  <tr>
    <td>3-C2 Observe user public key.
      <br>See 3-C1.
    </td>
    <td>2-A2 Delete or damage the secret.
      <br>Counter:
      <br>(1) user is encouraged to back up the secret
      <br>(2) freeze secret into memory
    </td>
    <td rowspan="5"></td>
  </tr>
  <tr>
    <td>4-A1 Trick user to break Kampela.
      <br>Counter:
      <br>(1) Backups. And cheap enough Kampela.
    </td>
    <td>2-A3 Delete address.
      <br>Counter:
      <br>(1) encourage back-up
    </td>
  </tr>
  <tr>
    <td>6-C1 Discover log or public keys through the app.
      <br>Counter:
      <br>(1) app may have an association of some public keys; separate app is suggested for Super Secret Derivation;
      <br>(2) log for each public key is already on-chain and public
    </td>
    <td>2-A4 Delete specs.
      <br>Counter:
      <br>(1) Only possible on already unlocked Kampela.
    </td>
  </tr>
  <tr>
    <td rowspan="2"></td>
    <td>3-A1 EMP.
      <br>Counter:
      <br>(1) Backups. And cheap enough Kampela.
    </td>
  </tr>
  <tr>
    <td>4-I7 Message with not printable symbols and/or metasymbols
      <br>Counter:
      <br>(1) display message and hexadecimal payload, and possibly highlight undisplayable symbols
    </td>
  </tr>
</table>

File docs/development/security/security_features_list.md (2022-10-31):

## Hardware
- Touch screen for data entering on Kampela. Shuffling buttons on pin entering. Stable keyboard for text entering.
- Additional removeable token required when entering the pin.
- Personalized Kampela.
- PUF on crypto chip.
- Kampela is active only briefly after disconnect with companion device. Kampela is not powered.
- Kampela firmware can't be changed unless Kampela is physically opened, or in "hacker edition".
- Tamper-evident casing.
- Inner circuit produces minimal noise.
- Build signature is checked on-board.
- Self-destruction can be initiated on Kampela only locally, no api for remote one or one through companion device.
- Self-destruction must be available without the detachable token or any other authorization.
- Casing of Kampela does not allow companion device camera to see the sensitive data screen.

## Firmware
- Kampela stores all derivations created on it.
- Kampela is able to display derivation path as hex combination.
- All incoming data must be parsed in Kampela and displayed to user.
- Signatures for all verifiable data must be checked on Kampela.
- Forbid blind signing.
- Sufficiently complex pin.
- Limit the number of pin entering attempts before Kampela is irreparably blocked.
- Request pin when accessing the secret (backup, signing).
- Request pin when adding data into Kampela.
- Kampela can receive payloads only from introduces companion devices.
- Freeze the secret.
- Request pin when introducing a new companion device.
- Message parsing displays both text and hex, with highlighted suspicious symbols in hex.

## Supply chain
- Trustworthy and mass-produced crypto chip.
- Verification challenge for crypto chip.
- Factory QA.
- Firmware has reproducible builds.
- Kampela is cheap and is easily replaceable.

## User materials
- User instructions and manuals (both physically printed and online)

## Ecosystem
- Support verifier system.
- Warn on companion device side that a new Kampela is in action (this checks only removeable emitting token).

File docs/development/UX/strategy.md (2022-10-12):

# UX overview

The Kampela system consists of Kampela itself and optionally removable NFC token independent from the device but required for authorization and operation of the tool.

For proper signing operation, a hot wallet is required for input and output. In general, these could be two different wallets, the only requirement is that these are brought into network connection within reasonable time before and after transaction signing. In best case scenario there is just one duplex hot wallet.

An optional encoding device could be used if the input hot wallet does not support NFC interfacing.

Thus, we have 3-6 devices that should stay in close proximity of each other, within close distance from external network for Substrate access and user, that handles these devices.

# UX strategy

## Comfort of use

The device should be pleasant to use. Users would have to hold the phone and the Kampela as a stack and operate on it simultaneously. We should not add unnecessary difficulties on top of that. Things like metadata management should happen automatically and without users' help.

Stack configuration must be researched and determined. Possible options are:
- flip: Kampela screen is on the opposite side of the phone screen
- slide: Kampela screen is visible either under or over the phone screen
- book: Kampela screen is to the side of the phone screen

UI decisions on device shape and handling should be made based on live user tests with device mock models or prototypes.

## Friction

Similar to approach taken in Parity Signer development, certain allowed actions that require extra attention should result in friction. All transactions must be read and explicitly confirmed before accessing the secret storage. Removal/change of trust sources should be sufficiently difficult to stop users from doing it mindlessly.

## Forbidden actions

Certain actions should be forbidden altogether even if complete device replacement is the only alternative.

## Disposable Kampela

Users should be ready to get a new Kampela if something goes wrong. There should be a simple and clear safe disposal protocol that anyone could follow - even without authorization. Safe disposal is essentially the best scenario among DOS attacks (which are quite trivial with physical access to device) and should be encouraged.

## Personalization

Kampelas should be highly personalizable, probably in subtle ways. It should be trivial for owner to observe that the device was swapped.

## Few buttons

Due to power and computational limitation, on-board controls would be inevitably limited. Thus the buttons should be really good, reusable and easy to understand.

## Device versions

Users will not have access to device firmware (except for development model probably). Users may want to select own settings during the Kampela initialization (allow secret backup, allow verifier to be changed, block more than one derivation per device). These could be also factory-set so that there are just many different models of Kampela available for customers.

## Signer ecosystem

Kampela should fit nicely within Parity Signer ecosystem and - where possible - should adapt UI components from there.

## Utilize first use moment

The user will be really vigilant only once - on first use. Thus we should utilize this unique moment, minimize amount of annoying attention diluting things and maximize educational impact.

## Manuals

Kampela must be accompanied with sufficient instructions and manuals, possibly even in printed form.

## Migration

When migrating between devices, secret information should be entered anew, since there is no interdevice communication channel (and should not be). All non-secret information could be transferred through NFC from hot wallet; we need to establish the derivation export protocol akin to one used in Signer for batch derivation import, but with broader functionality to make migration as simple as possible (even though inevitably difficult due to seed phrase re-entry at least; see Friction section above).

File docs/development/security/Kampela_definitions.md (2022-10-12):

Core definitions: https://docs.substrate.io/reference/glossary/ 

Some definitions not listed above:
* pin code - human-friendly secret used by user for authentication with Kampela device. Should not be biometric;
* secret phrase - a seed phrase supported by Substrate key derivation protocol as derivation root;
* user - legal owner of Kampela device;
* identity - combination of address and proof of ownership of corresponding secret key;

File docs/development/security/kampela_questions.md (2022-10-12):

# How the user can check that the device matches the specs?

- No transmitting parts.
- Secure chip as specified.
- Functional RNG.
- No tampering (e.g. no change in software/hardware after device has left the factory).

Comments:
1. Not truly possible for user to check that RNG is indeed random. Any check would find only outrageous flaws and may erroneously assure user of safety.
2. User may check though that there is no signal emission.
3. Anti-tampering protection can assure user only of no out-of-factory tampering.

Notes:
1. User will have to trust the manufacturer to install correct hardware and software.
2. Users can and will disassemble their own devices, potential in-factory tampering can be revealed. Not much good for users already compromised though.

# What data is stored in Kampela and Kampela companion?

Each Kampela may have only one secret. Primitive hardware allows no convenient way to select secret and avoid confusion.

## Decision 1. Can the entered secret be corrected in Kampela?

Pros:
- Fix typos on start
- Flexible Kampela

Cons:
- Seed phrase swap(2-I4), also more silly things such as 2-A2

Possible solution: allow user to set secret and freeze it into memory separately.
Keep sufficiently annoying reminders to freeze the secret.
Note. Copious explanations in manual needed.

## Decision 2. What is protected by pin?

### Pin protects the access to secret storage.

Secret storage is activated when keypair is generated during:
- signing
- calculating public key for a new address

Modifying secret before it is frozen? Pin is used.

Adding or removing chain specs and chain verifiers? Secret not used. No pin. 2-I2, 2-I3, 2-A3.

Removing address if addresses are stored on Kampela? No pin. 2-A2.

### Pin both unlocks Kampela and protects secret storage.
Pros:
- Substantially more difficult to mess with specs, verifiers, addresses.

Cons:
- Pin is effectively entered twice all the time (annoying, too often used pin). Note: sensor moving buttons to avoid 2-I2?

### Two pins.
Cons:
- User will make them identical and simple on top of that. Or forgets them. Or both.

### Pin to access secret storage AND Kampela has a set of friendly devices
Kampela needs to be acquainted with companion device before use. This requires pin.
Companion device has unique identifier, Kampela stores all introduced devices identifiers (where? in db, next to chain specs?)
Of course, companion device can be banned.

Cons:
- Kampela safety with specs and verifiers depends on possibly always online companion device.
- User will loose access or will be staggered if companion phone is

Proposed solution: by default make user enter pin for unlocking and to access the secret.
Allow users remove pin entry on unlocking. If they live in the middle of a swamp and hate pins.

## Decision 3. What kind of secret is stored in Kampela?

Seed phrase ("bottom drive obey lake...")?
Secret key ("0xfac7959dbfe72f...")?
Any of them?

This doesn't make much difference for signing itself (combined secret construction is same).
The only difference is how user will load the secret in Kampela.

Manual entering through keyboard is possible for both options.

Allow both? Would this cause much confusion?

Allow both and strongly recommend seed phrase?

Allow both only in advanced mode settings? (proposed variant)

Allow only seed phrase?

Typing hex string may be more difficult (64 hex symbols, non-readable, unable to backup properly), but some users may need it.
Additionally, Kampela does not allow to change the secret once it is entered, typo probability is really high for secret key.

## Decision 4. Where are public keys and associated data stored?

To form a signature, Kampela needs the secret and full derivation path (soft `/`, hard `//`, password `///`).

Signable transaction contains public key and encryption algorithm to identify *who* signs the transaction.

Getting corresponding derivation path can happen in Kampela itself or in companion app.

### 4A Public keys and associated data are stored on Kampela

Companion in this case has to store only public keys.
Kampela searches for derivation by public key, calculates keypair, checks public key, calculates signature.

Cons:
- memory taken on Kampela
- resources (power) to make database search (unsure how relevant this is)
- Kampela stores non-secret data **together** that could cause confidentiality issues (1-C1, 2-C1)

Unclear: how is the password (`///`) for passworded accounts entered? Proposal: unicode symbols via hex combinations.

Perform confidentiality breach on Kampela seems more demanding than on companion (for starters, companion is online, Kampela needs physical stealing).

### 4B Public keys and associated data are stored on companion

Kampela stores nothing.

Kampela uses derivation to calculate keypair, compares public key with the one from signable transaction, calculates signature.

Kampela is still used to export public keys and data into companion when setting the companion up.

No particular difference between 4A and 4B. Public keys are on companion either way. Kampela has to have the ability to export public key data (as a QR) into companion either way.
Lean to storing derivations in Kampela, to avoid keys double export and user loosing derivation path (4-I6, 2-A5).

## Decision 5. Chain verifiers.

Each chain has a verifier, i.e. an address that is trusted to check and publish correct metadata and to lesser extent chain specs.

### Is entirely unverified data allowed?

Proposed: no by default. Allow in advanced settings.

Note. If the proposal to involve metadata hash in signing will pass, this changes to default yes.

## Decision 6. Chain specs.

Chain specs are used to display parsed transactions more conveniently.

### Does Kampela need to use them at all?

- base58 prefix could be in metadata; what if it is not?
- units-decimals could just be ignored; ugly, but users may not even care.

Pros:
- prettier display

Cons:
- more storage on Kampela
- verified specs, additional way to mess with user

Specs must be stored somewhere, at least to have genesis hash and chain name associated.

## Decision 7. Chain isolation.

Pros:
- user can not accidentally apply wrong address even if the clien does not separate chains

Cons:
- users can and will get confused. See Signer complains.

Also, if isolate: where?

Suggestion: isolate in companion.

## Decision 8. Is removing derivations from Kampela allowed?

Pros:
- typos
- user cleanup
- secret accounts created briefly to be used and then to be deleted until next use

Cons:
- accidentally or maliciously remove good derivation and there was no backup

## Decision 9. Software updates possibilities
Should Kampela be designed with software updates in mind? Even with prior testing, there is a chance that significant vulnerabilities or bugs will be found following the Kampela release.

Pros:
- it is possible to fix vulnerabilities and bugs after the release.

Cons:
- software updates introduce a new attack vector.
- we need a separate external program to handle the software updates.

Suggestion: forbid firmware updates, except in "hacker edition" (the one for user to play with and modify).

## Decision 10. Port for charging, debugging, and keyboard connection 
Kampela must be supplied by energy in one way or another. NFC charging is an option, but the device used for routine NFC communications (e.g. mobile phone) in general will not be able to charge Kampela. It will also be impractical to buy an NFC charging device just to charge Kampela.

Pros:
- easy to charge
- easy to get data from and into the device, especially useful while in development.

Cons:
- introduces a new attack vector. The user must make sure to not use a malicious cable.
- more sophisticated hardware and software

Suggestion: absolutely no data ports, this negates the whole point of the air-gapped device. Charging must be sufficient through NFC, and Kampela should not be alive/active more than a few seconds after NFC data transfer.

Keyboard for entering all secrets must be Kampela's own one, secrets must not be transferred in any way. Non-secret information could be entered on the phone and transferred to Kampela through NFC.

## Decision 11. How to personalize Kampela?

Stickers, watermarks, user drawings. This should be encouraged to make swap less possible.

Also, Kampela may be transparent (casing made from transparent or semi-transparent plastic) so that user can see that the device is not tampered with.

## Decision 12. End of life protocol

Must destroy device memory.

Can be activated only in physical contact. Quickly. But not accidentally.

Not through the companion and definitely not remotely.

Exact details must be decided based on specific components.

## Decision 13. Kampela got lost or was for some time unaccounted for

1. If user has lost Kampela, it must be assumed that the secret got exposed in the worst possible way. User must secure secret-associated assets ASAP on their own.

2. If user has lost and then found Kampela, it must be assumed to be tampered with. Kampela with unknown history must be disposed of properly (see the end of life protocol), due to a number of possible attacks involving device swap.

# Proposed design draft.

Kampela stores secret protected by pin.

Kampela stores data for each chain, protected by pin.
- genesis hash
- chain name
- base58, units, decimals

Say, Kampela creates addresses, does not store them, exports piblic key data as qr code.
Unclear. Double scan may be dangerous (companion device is online and assumed not secure), can export wrong public key this way.
Single scan from Kampela: how user keeps the derivations recorded then?
Also, loosing the derivation path is quite real.

If Kampela does not store the derivations, they are stored elsewhere, for example, in pjs. This is less confidential than Kampela behind the pin.
So maybe store the derivations after all.

If Kampela stores the derivations, it keeps:
- public key
- derivation
- pwd or no pwd
- encryption algorithm
- network(s)

# How user distinguishes addresses?

Imagine the mess: a few Kampelas (personal funds seed, work account seed, Very Important work account secret), lots of derivations (overlapping for different seeds, because `//polkadot` is a convenient default derivation), a few associated companion devices.

Identicons are not super effective here. They are blind-ish and if user has more than 10 to look at, they all look too similar.
Base58 addresses, hex representation - could be ok to check that account is correct, same as identicon, but not search with, probably.

User may want to give the account the name on creating. How and where? And what will prompt user to remember the derivations at all? How to distinguish identical derivations from different Kampelas?

Possible: create upon secret freezing the name for device. Keys would look like `DeviceName smth-smth` with `smth-smth` optionally entered by user on Kampela keyboard or rather the public part of derivation itself.

# Do we allow to change the pin?

Really?

# When pin is entered?

(1) when Kampela is just connected to companion phone
(2) when command is already formed and sent through companion phone
(3) right before the action (accept specs, create derivation, etc)

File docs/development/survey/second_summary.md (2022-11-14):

This is a summary of the Kampela survey results. 31 users participated in the survey. We divided users into three groups depending on their technical level:  

***Cryptocurrency users and enthusiasts***. This group consists of 14 users who use cryptocurrencies or consider themself blockchain enthusiasts, but do not work in blockchain-related business. This group is less technical but contains some active substrate users. Here 10/14 of users have not used substrate coins and 4/14 use them often or occasionally. Among this group, 10/14 of users do not use or do not know what account derivation is, while only 4/14 use multiple derivations or won't tell. 5/14 participants use hardware wallets. Wallets metioned: ledger * 3, ledger nano, trezor, safepal. Interestingly, the usage of derivations does not seem to correlate with the usage of hardware wallets here: among these users 1 participant does not use derivations, 1 does not know about them, and 1 won't tell, only 2 participants use multiple derivations.

***Employees in blockchain-related business***. This group consists of 10 users who are in the blockchain-related business, but are not blockchain developers. This group is very diverse. Here 6/10 participants have not used substrate coins, 3/10 participants used them several times and 1/10 participant uses substrate coins often or occasionally. Results on account derivation and hardware wallets contain all kinds of answers and show no discernable pattern.  

***Blockchain developers***. This group consists of 6 blockchain developers. Technically skilled and highly uniform group. Here 5/6 participants have used substrate coins, 5/6 use multiple account derivation, and 5/6 participants use hardware wallets.  

## Main results  
Three distinguished groups of participants may be discerned:  
* (1) Crypto users and enthusiasts – less technical, but  some are active substrate users;  
* (2) Very diverse group of employees in blockchain-related businesses;  
* (3) Technically minded and surprisingly uniform group of blockchain developers.  

Participants use a plethora of hardware wallets:
* Ledger        (6 mentions);  
* Parity signer (4 mentions);  
* Trezor        (3 mentions);  
* Ledger nano   (2 mentions);  
* Ledger nano S (1 mention);  
* Safepal       (1 mention).  
 
Users either use multiple derivations or do not know/do not use/won't tell about derivations at all. Only single user communicated about using one derivation.  

The overwhelmingly common user problem with current hardware wallets is the ease and accesibility, 8/31 participants did mention it, they are comming from all meantioned groups. Exact responses are:
* "design and accesibility (User Friendliness)", response by employee in blockchain business;
* "Not easy to use", response by cryptocurrency user;
* "I would like to see more user friendly hardware wallets that are easier to understand and navigate", response by employee in blockchain business;
* "better and simple interface for dummies", response by cryptocurrency user;
* "slow interface (buttons)", response by cryptocurrency user;
* "I'm lazy for buying and using it", response by cryptocurrency user;
* "Ease of getting to approval", response by blockchain developer;
* "ugly ux", response by blockchain developer.

Closed source hardware and software is only reported as an issue by 3/31 participants.  

Users are indeed secretive: only 5/31 people decided to leave their names, and only 8/31 people left their e-mails.

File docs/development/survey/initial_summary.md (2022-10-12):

# General information

(survey link)[https://cryptpad.fr/form/#/2/form/view/TUMvvTbGw2JpWbUanilxfIMgnW8UAfL4+KAvpyCk+UE/]

**Survey goal:** Define user groups, collect contacts for future surveys

# Hypothesis

From Parity Signer's development, it is know that:

1. All users are generally extremely secretive and unwilling to share their usage information, even privately and for common good
2. There are 3 general groups of users:

   2.1. **"Stakeholder":** casual user with 1 key per device that only uses it for authorizations and multisignatures when managing large assets.

   2.2. **"Power user":** has many accounts and complex derivation schemes, uses many features at once. Every setup is unique and significantly different from others.

   2.3. **"Hacker":** wants to use cryptowallet with security features overriden, modify it, does not want safeduards.

# Data collection

The survey was distributed in Russian and English versions in social networks relevant to ecosystem development. Total 24 responses were collected over approximately 3 weeks time, which confirms H1. 4 explicit contacts for future analysis were acquuired.

# Data analysis

With this limited amount of data, detailed statistics is not feasible.

## General information

All respondents use cryptocurrency in one way or another.

9/24 respondents never used Substrate ecosystem, notably there are no developers in this group.

Other hardware storage tools mentioned were:

- Parity Signer
- Ledger/Ledger Nano
- Trezor
- AirGap Wallet

## Derivations usage

Out of all respondents, 8/24 claimed not to use derivations, 4/24 did not know what it is. Notably, no responses were collected claiming use of derivations outside of Substrate ecosystem, although it's not ecosystem-unique.

Out of users within Substrate ecosystem, 3/15 responded that they do not use derivations, and 3/15 refused to tell. One user in that group did not know what derivations are.

No significant correlation was observed between user role in ecosystem and use of derivations. This is certainly due to lack of data, but it is also quite clear that there are 1-address developer users and multiadress stakeholders.

## Suggestions

Users have noted poor usability of hardware wallets.

As always in similar discussion, hassle of metadata updates and lack of available manuals was noted. Demand for simpler version of everything was observed.

Ledger's low rate of updates was mentioned as unacceptable.

Users want support of Shamir secret sharing integrated.

Users care about whole system being opensource.

Users mentioned that they value mechanical robustness and quality of build.

One of the key demands for key managers noted from the feedback is a deep integration into existing wallets, as opposed to making a new app. Wallets development naturally lags behind the chains development, and adding more complexity on top of that would significantly decrease the usability of Kampela.

# Conclusions

1. We need to keep collecting information. Fortunately, the project is organized in a way that we could easily keep collecting data and reevaluating analysis till the end, relying on the latest information to plan the next stage.

2. H1 seems to be confirmed. There is still hope that users would become more open and willing to cooperate as project moves through milestones 3 and 4 delivering more tangible and visualizable results and we will suddenly have more high quality information.

3. 4 competing well-known key management systems were identified. We should learn from those systems, try to adapt their strong sides and fix their shortcomings.

4. We should limit the need to update firmware or perform any complicated metadata updates. Ideally Kampela should be usable at all times and in case of global breach just be recalled or replaced by users.

5. We should focus on standard communication protocol and integration into existing wallets (at least Nova who actively collaborates and helped us gather data for this report). We could also synergize this project into our proposal in making for a functionality-centered wallet project Kiondo.

6. We should remember to include banana split recovery protocol on-board.

7. Users do not seem to differentiate by roles in ecosystem, but rather by their technical skill and expected attack routes. We should reconsider user types classification. Fortunately, we have a list of user desires, and we can collect more data on this later, since we have a couple of milestones ahead before complete prototype design.

8. Users need to be forced to see the manual. Indeed, with hardware distribution, we could include instruction manual printouts with delivered package and make people want to read it. At the same time, large fraction of tutorials should be devoted to companion apps - wallets, we should come up with strategy on improving their clarity or at least somehow facilitate it.

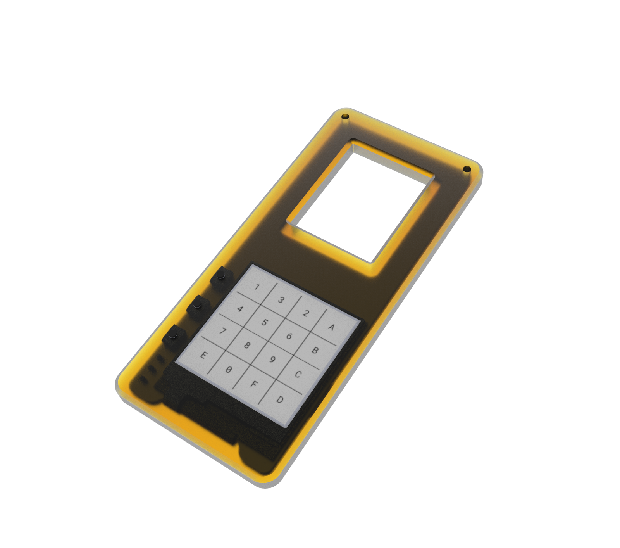
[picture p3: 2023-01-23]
hardware/development/Kampela_C1_enclosure/renders/kampela_3_milestone.50.png

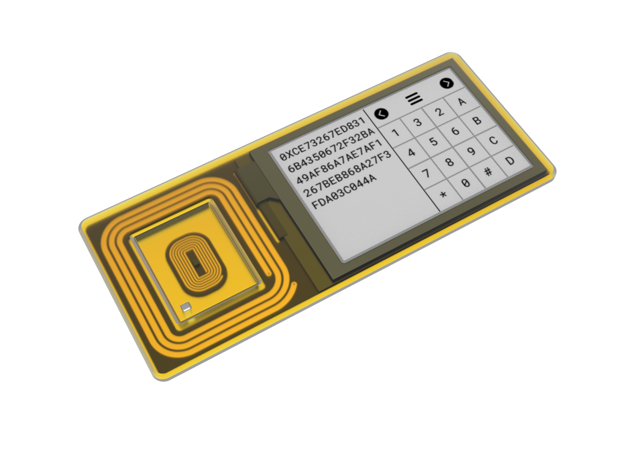
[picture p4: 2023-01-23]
hardware/development/Kampela_C1_enclosure/renders/kampela_2.7_einc_touch.48.png

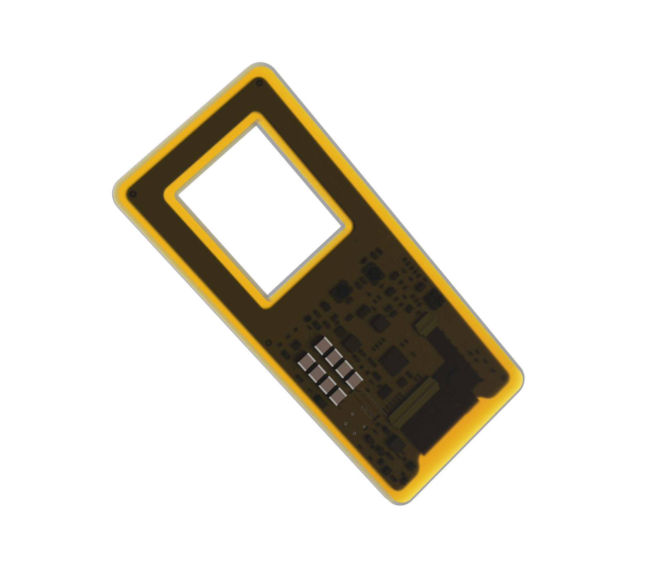
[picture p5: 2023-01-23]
hardware/development/Kampela_C1_enclosure/renders/kampela_3_milestone.51.png

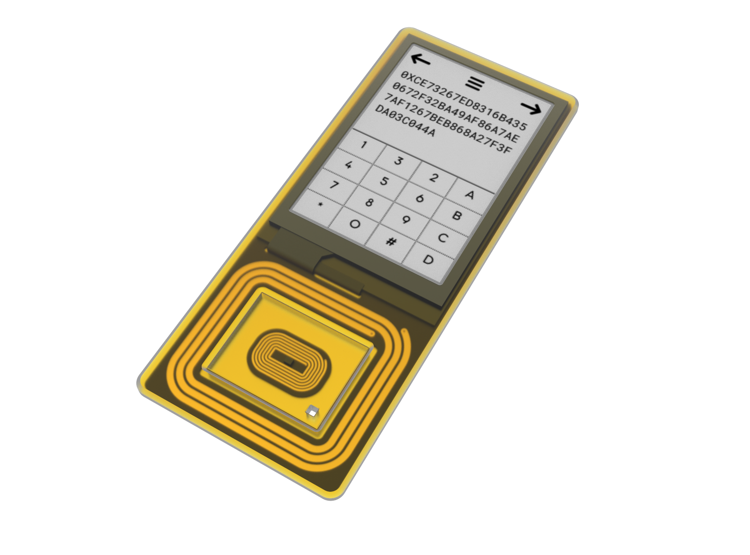
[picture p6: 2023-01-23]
hardware/development/Kampela_C1_enclosure/renders/kampela_2.7_einc_touch.49.png

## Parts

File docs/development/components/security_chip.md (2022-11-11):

## Ledger insides

### Known images

official website:

<https://support.ledger.com/hc/article_attachments/4406450402961/LedgerNanoX_PCB_rev1.jpg>

<https://support.ledger.com/hc/article_attachments/4404778576401/front_pcb.png>

<https://support.ledger.com/hc/article_attachments/4410975918481/revision_3_front.jpg>

<https://support.ledger.com/hc/article_attachments/4410972052497/revision_4_front.jpg>

better quality pic: <https://twitter.com/walletfail/status/1129328479865065473>

### Recognizeable details

1. <https://www.mouser.fi/ProductDetail/STMicroelectronics/STM32WB55CCU6?qs=vLWxofP3U2waGkUGKmQZWQ%3D%3D>

2. Ledger argues extensively that the secure element is more preferable than safe memory chip:
<https://www.ledger.com/academy/security/not-all-chips-are-born-equal>

Secure element is not open-source, though.

The security chip in pics referenced above is apparently the one Ledger-marked.

"Ledger J2M...", produced by ST.

It is possible that the chip is a close relative of this one:

<https://www.st.com/en/secure-mcus/st33j2m0.html>

3. There are no hardware-based Schnorkkel supporting ICs, thus the making and using of at least Sr25519 pairs will possibly happen outside the security chip.

We would have to rely on memory zeroize in the chip that does the calculations.

Also, see this: <https://thenextweb.com/news/ledger-nano-s-hack-cryptocurrency>

(And how do *we* ensure that the chip is genuine?)

## PUF chips

### Maxim

Maxim provides a number of PUF chips:

- <https://datasheets.maximintegrated.com/en/ds/MAX32520.pdf> microcontroller to combine secret storage and calculations

- <https://datasheets.maximintegrated.com/en/ds/DS28E38.pdf> secure verifiable storage, with ECDSA; calculate pairs externally;

- <https://datasheets.maximintegrated.com/en/ds/DS28E50.pdf> secure verifiable storage, with SHA-3; calculate pairs externally;

### Silabs

Silabs provides MCUs with PUF:

<https://www.silabs.com/documents/public/data-sheets/efm32pg23-datasheet.pdf>

(B model)

### Microchip

<https://www.microchip.com/en-us/products/security/secure-mpus>

Microchip claims PUF in MPUs. Some undisclosed tamper protection with docs available apparently only through NDA.
Datasheets discuss only anti-tamper pins.

- <https://ww1.microchip.com/downloads/aemDocuments/documents/CPG/ProductDocuments/ProductBrief/CEC173x_Data_Brief.pdf> PUF specifically claimed here

- FPGA <https://www.microchip.com/en-us/products/fpgas-and-plds/system-on-chip-fpgas/polarfire-soc-fpgas>

### NXP

- <https://www.nxp.com/docs/en/fact-sheet/P71D321.pdf> PUF claimed, need to check actual datasheets.

- <https://www.nxp.com/docs/en/data-sheet/LPC540xx.pdf>

- <https://www.nxp.com/docs/en/data-sheet/LPC54018JxM-LPC54S018JxM.pdf>

- <https://www.nxp.com/docs/en/data-sheet/LPC55S0x_LPC550x_DS.pdf>

- <https://www.nxp.com/docs/en/nxp/data-sheets/LPC55S1x_LPC551x_DS.pdf> (USB)

- <https://www.nxp.com/docs/en/nxp/data-sheets/LPC55S2x_LPC552x_DS.pdf> (USB)

- <https://www.nxp.com/docs/en/nxp/data-sheets/LPC55S6x_DS.pdf> (USB)

Document on usage: <https://www.nxp.com/docs/en/application-note/AN12324.pdf>

### Notes

1. We do not protect the user secret after it was decoded from side channel attacks, because at this point it could be read on backup.
We only protect from the unauthorized decoding itself.

2. How good is PUF actually? (i.e. how much enthropy it really provides? what about these articles claiming PUF can be predicted? what kind of PUFs are there after all in each case?)

3. All microcontrollers are based on 32-bit ARM Cortex-M4F, or -M33, or -M4.

## Other security ICs

### Infineon

1. <https://www.infineon.com/cms/en/product/security-smart-card-solutions/cipurse-products/>
Some chips, for example, CIPURSE have NFC interface, not acceptable.

2. Government ID applications chips have EAL6+ certification.

<https://www.mouser.fi/datasheet/2/196/Infineon_OPTIGA_TRUST_M_SLS32AIA_DataSheet_v03_00_-1927815.pdf>

None of the chips boast PUF.
Datasheets claim "tamper proof NVM". Need additional info on that.

3. Trusted computing modules have EAL4+

<https://www.mouser.fi/datasheet/2/196/Infineon_OPTIGA_TPM_SLB_9673_FW26_DataSheet_v01_01-3006843.pdf>

### STMicroelectronics

<https://www.st.com/en/secure-mcus/secure-hardware-platforms.html>

There is a number of MCUs certified with EAL6+, but no PUF actively presented.

## Other notes

<https://trustedcomputinggroup.org/membership/certification/>

TCG appears to provide good indication of interoperability, but the criteria are quite obscure.

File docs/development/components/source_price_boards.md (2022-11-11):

# MCUs

<table>
  <tr>
    <th>Manufacturer</th>
    <th>Part name</th>
    <th>ARM Cortex</th>
    <th>Mouser reference</th>
    <th>unit price range, €
      <br>(price varies with configuration,
      <br>check individual links for details,
      <br>some items are not stocked)
    </th>
    <th>dev board Mouser reference</th>
    <th>dev board datasheet</th>
    <th>dev board price, €</th>
  </tr>
  <tr>
    <td>Maxim Integrated</td>
    <td><a href = "https://datasheets.maximintegrated.com/en/ds/MAX32520.pdf">MAX32520</a></td>
    <td>M4F</td>
    <td><a href = "https://www.mouser.fi/ProductDetail/Maxim-Integrated/MAX32520-BNJ%2b?qs=Cb2nCFKsA8qkKONGxfGE0Q%3D%3D">MAX32520-BNJ+</a>
      <br><a href = "https://www.mouser.fi/ProductDetail/Maxim-Integrated/MAX32520-BNS%2b?qs=XeJtXLiO41RukBM3%2FOD4eA%3D%3D">MAX32520-BNS+</a>
      <br><a href = "https://www.mouser.fi/ProductDetail/Maxim-Integrated/MAX32520-BNS%2bT?qs=Cb2nCFKsA8pDEWnZFUM0pw%3D%3D">MAX32520-BNS+T</a>
    </td>
    <td>8.99 (1 pc MAX32520-BNJ+ or MAX32520-BNS+)
      <br>5.55 (2500 pcs MAX32520-BNS+T)
    </td>
    <td><a href = "https://www.mouser.fi/ProductDetail/Maxim-Integrated/MAX32520FTHR?qs=GedFDFLaBXFK0tsk1nYxYQ%3D%3D">MAX32520FTHR#</a></td>
    <td><a href = "https://www.mouser.fi/datasheet/2/256/MAX32520FTHR-1878436.pdf">MAX32520FTHR# datasheet</a></td>
    <td>44.65</td>
  </tr>
  <tr>
    <td>Silicon Labs</td>
    <td><a href = "https://www.mouser.fi/datasheet/2/368/efm32pg23_datasheet-2952668.pdf">EFM32PG23B</a></td>
    <td>M33</td>
    <td><a href = "https://www.mouser.fi/c/?q=EFM32PG23B">EFM32PG23B search</a>
    </td>
    <td>5.18 (1 pc)
      <br>2.71 (100 pcs)
    </td>
    <td><a href = "https://www.mouser.fi/ProductDetail/Silicon-Labs/PG23-PK2504A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">PG23-PK2504A</a></td>
    <td><a href = "https://www.silabs.com/documents/public/user-guides/ug515-efm32pg23-brd2504a-user-guide.pdf">EFM32PG23 Pro Kit user guide</a></td>
    <td>82.16</td>
  </tr>
  <tr>
    <td>Microchip</td>
    <td><a href = "https://ww1.microchip.com/downloads/aemDocuments/documents/CPG/ProductDocuments/ProductBrief/CEC173x_Data_Brief.pdf">CEC173x</a></td>
    <td>M4F</td>
    <td><b>currently not stocked</b>
      <br><b>Mouser, Digikey, Microchip</b>
      <br><a href = "https://www.mouser.fi/ProductDetail/Microchip-Technology/CEC1736-S0-I-2HW?qs=MyNHzdoqoQIKL7do0PVtKg%3D%3D">CEC1736-S0-I/2HW</a>
      <br><a href = "https://www.mouser.fi/ProductDetail/Microchip-Technology/CEC1736-S0-I-2ZW?qs=MyNHzdoqoQKKysu9RtbiJQ%3D%3D">CEC1736-S0-I/2ZW</a>
      <br><a href = "https://www.mouser.fi/ProductDetail/Microchip-Technology/CEC1734-S0-I-2HW?qs=T%252BzbugeAwjj5uBU4uZArDQ%3D%3D">CEC1734-S0-I/2HW</a>
      <br><a href = "https://www.mouser.fi/ProductDetail/Microchip-Technology/CEC1734-S0-I-2ZW?qs=MyNHzdoqoQIzf8N6hI3zdw%3D%3D">CEC1734-S0-I/2ZW</a>
    </td>
    <td>8.77 (360 pcs) for CEC1736-S0-I/2HW
      <br>9.79 (520 pcs) for CEC1736-S0-I/2ZW
    </td>
    <td><a href = "https://www.mouser.fi/ProductDetail/Microchip-Technology-Atmel/EV19K07A?qs=vvQtp7zwQdNHBcN7uyQkNw%3D%3D">EV19K07A on Mouser</a>
      <br><a href = "https://www.microchipdirect.com/dev-tools/EV19K07A?productLoaded=true&allDevTools=true">EV19K07A on Microchip website</a>
    </td>
    <td><a href = "https://www.mouser.fi/datasheet/2/268/CEC1736_Dev_Board_Users_Guide-2997808.pdf">CEC1736 dev board user guide</a></td>
    <td>437.58 on Mouser (<b>not stocked</b>)
      <br>402.61 on Microchip website
    </td>
  </tr>
  <tr>
    <td rowspan = "5">NXP</td>
    <td><a href = "https://www.nxp.com/docs/en/data-sheet/LPC540xx.pdf">LPC54S0xx</a>
      <br><a href = "https://www.nxp.com/docs/en/data-sheet/LPC54018JxM-LPC54S018JxM.pdf">LPC54S018JxM</a>
    </td>
    <td>M4</td>
    <td><a href = "https://www.mouser.fi/c/semiconductors/embedded-processors-controllers/microcontrollers-mcu/arm-microcontrollers-mcu/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">LPC54S0 search</a></td>
    <td>15.37 (1 pc LPC54S018J4MET180E)
      <br>6.81 (540 pcs LPC54S005JBD100E)
    </td>
    <td><a href = "https://www.mouser.fi/ProductDetail/NXP-Semiconductors/LPC54S018-EVK?qs=l7cgNqFNU1h800G13pYJTQ%3D%3D">LPC54S018-EVK, with S018 onboard</a>
       <br><a href = "https://www.mouser.fi/ProductDetail/NXP-Semiconductors/LPC54S018M-EVK?qs=9r4v7xj2Lnlz71dwzcH6cA%3D%3D">LPC54S018M-EVK (<b>out of stock</b>)</a>
    </td>
    <td><a href = "https://www.mouser.fi/datasheet/2/302/NXP_01112019_LPC54S018_EVK-1891947.pdf">LPC54S018_EVK datasheet</a></td>
    <td>101.64</td>
  </tr>
  <tr>
    <td><a href = "https://www.nxp.com/docs/en/data-sheet/LPC55S0x_LPC550x_DS.pdf">LPC55S0x</a></td>
    <td>M33</td>
    <td><a href = "https://www.mouser.fi/c/semiconductors/embedded-processors-controllers/microcontrollers-mcu/arm-microcontrollers-mcu/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">LPC55S0 search</a></td>
    <td>7.72 (1 pc LPC55S06JBD64E)
      <br>3.03 (2000 pcs LPC55S04JHI48J)
    </td>
    <td><a href = "https://www.mouser.fi/ProductDetail/NXP-Semiconductors/LPC55S06-EVK?qs=DPoM0jnrROUohGVbwO6AIQ%3D%3D">LPC55S06-EVK</a></td>
    <td><a href = "https://www.mouser.fi/datasheet/2/302/LPCXpresso55S06UM-1919803.pdf">LPC55S06-EVK datasheet</a></td>
    <td>48.30 (<b>out of stock</b>)</td>
  </tr>
  <tr>
    <td><a href = "https://www.nxp.com/docs/en/nxp/data-sheets/LPC55S1x_LPC551x_DS.pdf">LPC55S1x</a></td>
    <td>M33</td>
    <td><a href = "https://www.mouser.fi/c/semiconductors/embedded-processors-controllers/microcontrollers-mcu/arm-microcontrollers-mcu/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">LPC55S1 search</a></td>
    <td>10.00 (1 pc LPC55S16JBD100E)
      <br>3.79 (800 pcs LPC55S14JBD64K)
    </td>
    <td><a href = "https://www.mouser.fi/ProductDetail/NXP-Semiconductors/LPC55S16-EVK?qs=vHuUswq2%252Bsxm6guyIPNHag%3D%3D">LPC55S16-EVK</a></td>
    <td><a href = "https://www.mouser.fi/datasheet/2/302/UMLPCXPRESSO55S16-1816275.pdf">LPC55S16-EVK datasheet</a></td>
    <td>52.33 (<b>out of stock</b>)</td>
  </tr>
  <tr>
    <td><a href = "https://www.nxp.com/docs/en/nxp/data-sheets/LPC55S2x_LPC552x_DS.pdf">LPC55S2x</a></td>
    <td>M33</td>
    <td><a href = "https://www.mouser.fi/c/semiconductors/embedded-processors-controllers/microcontrollers-mcu/arm-microcontrollers-mcu/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">LPC55S2 search</a></td>
    <td>10.61 (1 pc LPC55S28JBD100K)
      <br>4.79 (1500 pcs LPC55S26JBD64Y)
    </td>
    <td><a href = "https://www.mouser.fi/ProductDetail/NXP-Semiconductors/LPC55S28-EVK?qs=%252B6g0mu59x7JZAESiiGBB2g%3D%3D">LPC55S28-EVK</a></td>
    <td><a href = "https://www.nxp.com/document/guide/getting-started-with-the-lpc55s28-evk-evaluation-board:GS-LPC55S28-EVK">LPC55S28-EVK getting started manual</a></td>
    <td>49.56</td>
  </tr>
  <tr>
    <td><a href = "https://www.nxp.com/docs/en/nxp/data-sheets/LPC55S6x_DS.pdf">LPC55S6x</a></td>
    <td>M33</td>
    <td><a href = "https://www.mouser.fi/c/semiconductors/embedded-processors-controllers/microcontrollers-mcu/arm-microcontrollers-mcu/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">LPC55S6 search</a></td>
    <td>12.56 (1 pc LPC55S69JBD100K)
      <br>5.05 (480 pcs LPC55S66JBD64E)
    </td>
    <td><a href = "https://www.mouser.fi/ProductDetail/NXP-Semiconductors/LPC55S69-EVK?qs=0lSvoLzn4L%252BrouXqaTJJsQ%3D%3D">LPC55S69-EVK</a>
      <br><a href = "https://www.mouser.fi/ProductDetail/NewAE/NAE-CW308T-LPC55S69?qs=PzGy0jfpSMt2GdLPAjxy4A%3D%3D">NAE-CW308T-LPC55S69 (<b>does not ship to Finland</b>)</a>
    </td>
    <td><a href = "https://www.nxp.com/document/guide/getting-started-with-the-lpc55s69-evk-evaluation-board:GS-LPC55S69-EVK">LPC55S69-EVK getting started manual</a></td>
    <td>49.56 (<b>out of stock</b>)</td>
  </tr>
</table>

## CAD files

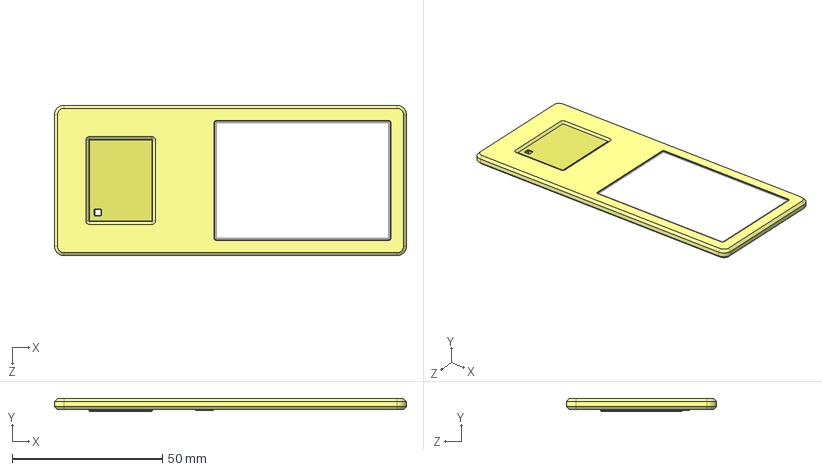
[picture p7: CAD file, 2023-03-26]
hardware/development/Kampela_C1_enclosure/dummy/2.7_e-inc_touch_design_44x38coil.STEP
117.0 x 4.20 x 50.0 mm
SOT23-5 x 4
res_0402 x 9
cap_0402 x 6
QFN36_0.5mm_6x6
2.7_einc_touch_pcb_44x38coil
GDEY027T91-T01 - bended
Silicone_2.7_einc_touch_44x38coil
Копия PCB_ST25^ST25_key_2.7_e-inc_touch_design_44x38coil
Копия Silicone_ST25^ST25_key_2.7_e-inc_touch_design_44x38coil

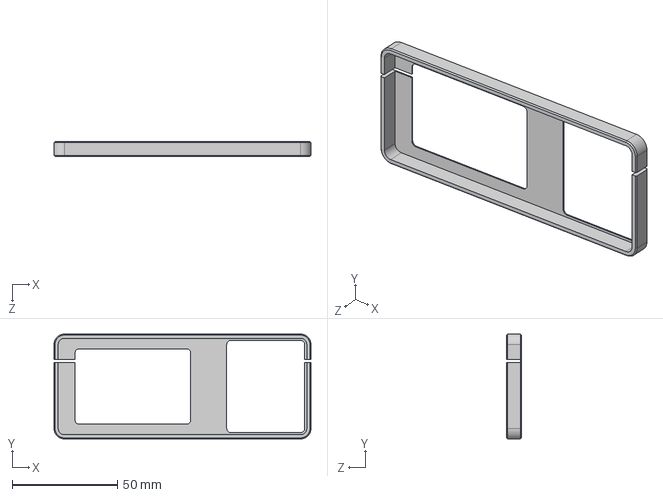
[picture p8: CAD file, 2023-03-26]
hardware/development/Kampela_D1_enclosure/kampela_D1_frame.STEP
122.0 x 49.8 x 7.00 mm

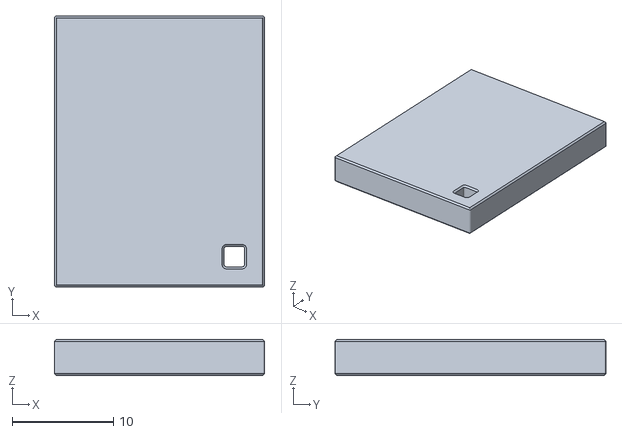
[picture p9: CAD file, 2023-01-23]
hardware/development/Kampela_C1_enclosure/dummy/ST25_key_2.7_e-inc_touch_design_44x38coil_small.STL
20.8 x 26.8 x 3.60

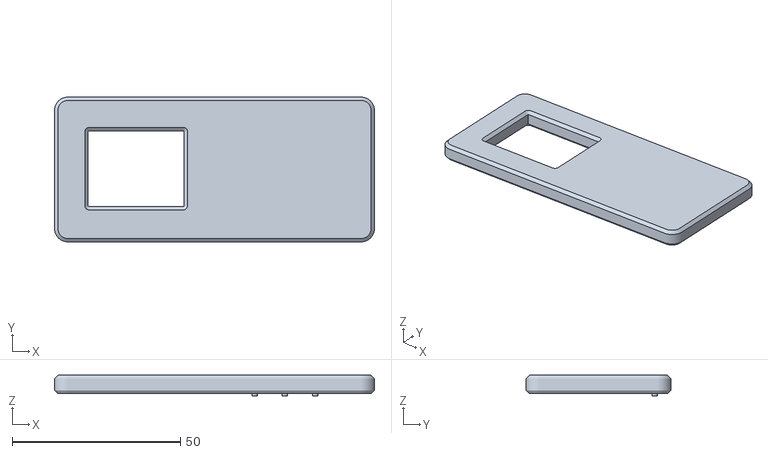
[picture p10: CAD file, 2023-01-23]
hardware/development/Kampela_C1_enclosure/models/kampela_3_milestone_3d_models/Silicone_3_milestone.STL
95.0 x 43.0 x 6.14

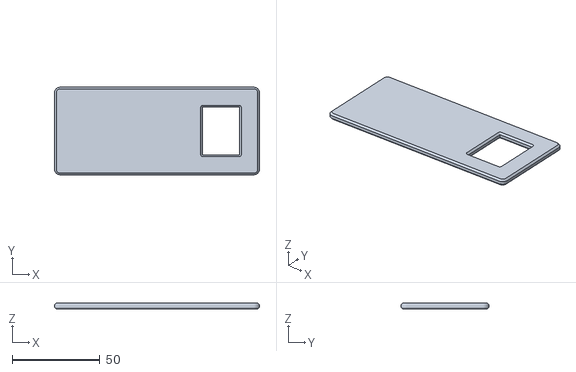
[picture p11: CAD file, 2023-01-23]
hardware/development/Kampela_C1_enclosure/dummy/Silicone_2.7_einc_touch_44x38coil.STL
117.0 x 50.0 x 3.60

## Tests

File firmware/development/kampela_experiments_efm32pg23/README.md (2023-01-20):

# Overview  

This is out first attempt to use `efm32pg23` chip for Kampela purposes.  

It mostly deals with security element (SE) basic functionality and with creating and using the keys from seeds.

The code is build for [`EFM32PG23B310F512IM48-C`](https://www.silabs.com/mcu/32-bit-microcontrollers/efm32pg23-series-2/device.efm32pg23b310f512im48) and tested with [`PG23-PK2504A`](https://www.silabs.com/development-tools/mcu/32-bit/efm32pg23-pro-kit?tab=overview) devboard.  

What it does:  

- creates AES-GCM wrapped key that will be used to encrypt and decrypt the user secret
- encrypts user secret, decrypts it back using the key (also needs internal IV data and user pincode - both are hardcoded at the moment)
- creates random `u8` slices with given length, to be used, for example, as entropy when a new seed is generated
- generates seed phrase from entropy and entropy from seed phrase (following `tiny-bip39`, draft-rewritten for `no_std`)
- generates seed from seed phrase (following `substrate-bip39`, draft-rewritten for `no_std`)
- cuts derivation data received as `&str` info separate junctions (following `sp_core`, draft-rewritten for `no_std`)
- creates `Ed25519` keypair, makes derivations (hard-only), signs, verifies signature (uses `sp_core` in `full_crypto` mode)
- creates `Sr25519` keypair, makes derivations (both hard and soft), signs, verifies signature (uses `schnorrkel` with external rng); note: `sp_core` in `full_crypto` mode does not support external rng thus causing the soft derivations and signing to panic)
- creates `Ecdsa` keypair, makes derivations (hard-only), signs (uses `sp_core` in `full_crypto` mode, verification apparently requires too much memory (?!) and is not yet added; maybe will switch to other ecdsa crate eventually).

- blinks with devboard left and right LED lights to indicate error codes and/or to signal program start and completion

# Prerequisites  

- `thumbv8m.main-none-eabihf` target, for Cortex-M33 with FPU
- nightly toolchain for this target
- [`arm-none-eabi-binutils`](https://archlinux.org/packages/community/x86_64/arm-none-eabi-binutils/) on ArchLinux
- [`Simplicity Commander`](https://community.silabs.com/s/article/simplicity-commander?language=en_US)

# Notes on build and testing  

1. The allocator used here currently (`embedded-alloc`) requires nightly toolchain.  

Switch to nightly with your preferred method, e.g.  

(while in `/app` folder)

`$ rustup override set nightly`  

2. While in `/app` folder, build the app:  

`$ cargo build --release`

File `app` in `/app/target/thumbv8m.main-none-eabihf/release/` is the `.elf` file.

Rename it into `app.elf`.

3. Transform `.elf` file into `.bin` file, e.g.  

(while in `/app/target/thumbv8m.main-none-eabihf/release/`, on ArchLinux)

`$ arm-none-eabi-objcopy -O binary app.elf app.bin`

4. Upload the `.bin` file. `Simplicity Commander` does the job.

5. If the `.bin` file loaded correctly, the program will start running.  

Devboard signals that it is alive and did not panic yet by occasional blinking.  

Currently, it blinks left LED 10 times on start, and right LED 10 times on finish.  

If a panic occurs, the right LED blinking will never be observed.  

So far the debugging was straightforward enough so that the blinking signals were sufficient for it.

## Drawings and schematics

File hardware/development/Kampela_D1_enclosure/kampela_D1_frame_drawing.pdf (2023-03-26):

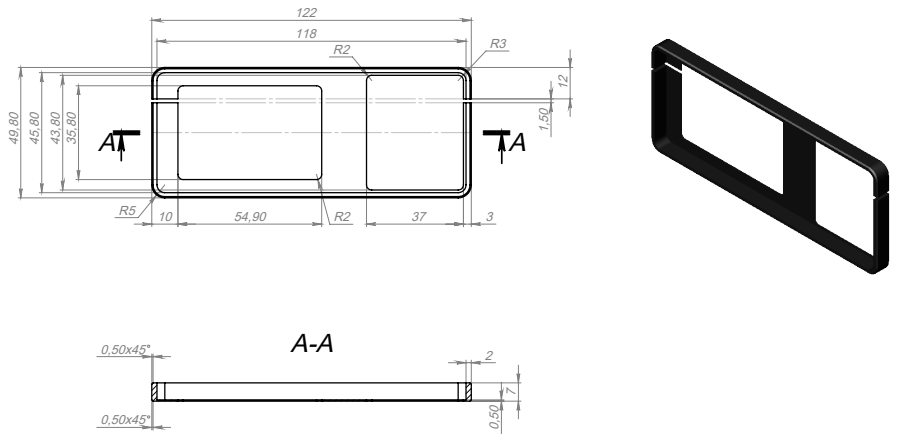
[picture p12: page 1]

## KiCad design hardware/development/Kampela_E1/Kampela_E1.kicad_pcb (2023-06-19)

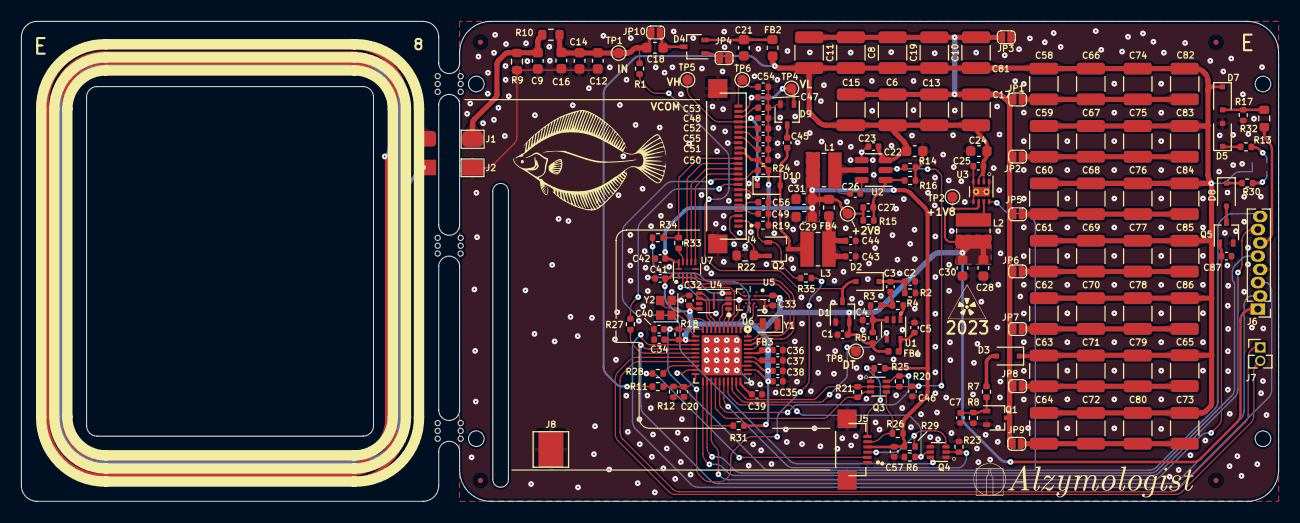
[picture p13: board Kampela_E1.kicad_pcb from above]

Board: 2 copper layers, 120.5 x 46.0 mm, 188 parts (1 on the bottom side), 95 nets.

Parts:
C1, C4, C5, C20, C23, C25, C26, C32, C33, C35, C36, C37, C38, C40, C41, C42, C46: 0.1u; C_0402_1005Metric
C2: 82p; C_0402_1005Metric
C3, C27: 100p; C_0402_1005Metric
C6, C8, C10, C11, C13, C15, C17, C19, C58, C59, C60, C61, C62, C63, C64, C65, C66, C67, C68, C69, C70, C71, C72, C73, C74, C75, C76, C77, C78, C79, C80, C81, C82, C83, C84, C85, C86: 47x16; C_1210_3225Metric
C7: 1uF; C_0402_1005Metric
C9: NC; C_0603_1608Metric
C12, C14: 47; C_0603_1608Metric
C16: 100; C_0603_1608Metric
C18: 68; C_0603_1608Metric
C21, C22, C24: 10x16; C_0603_1608Metric
C28, C29, C30, C31: 22x6.3; C_0603_1608Metric
C34, C43, C45, C49, C52, C53, C56, C57, C87: 4.7x25; C_0402_1005Metric
C39, C47, C48, C50, C51, C54, C55: 1x50; C_0402_1005Metric
C44: 0.1; C_0402_1005Metric
D1: BAV99W; SOT-323_SC-70
D2, D7, D10: BAT54WS; D_SOD-323F
D3: BZX84J-B9V1; D_SOD-323F
D4, D9: BAS70-04W; SOT-323_SC-70
D5: D3Z13BF-7; D_SOD-323F
D8: D3Z5V1BF-7; D_SOD-323F
D12: SB0603WC01-RG; LED_DUAL_0603
FB1, FB3: BLM15AG102SZ1D; L_0402_1005Metric
FB2, FB4: BLM18KG102SN1D; L_0603_1608Metric
FID1, FID2, FID3, FID4: Fiducial; Fiducial_0.5mm_Mask1.5mm
H1, H2, H3, H4: MountingHole; MountingHole_2.1mm
J1, J2, J8: E_ANT; TestPoint_Pad_2.4x3.5mm
J4: E2154CS0C1; GDEY027T91-T01_bended
J5: TOUCH; HRS_FH34SRJ-6S-0.5SH(50)
J6: Conn_01x08; PinHeader_1x08_P1.27mm_Vertical_Prog
J7: Conn_01x02; PinHeader_1x02_P1.27mm_Vertical
JP1, JP2, JP3, JP4, JP5, JP6, JP7, JP8, JP9, JP10: SolderJumper_2_Open; SolderJumper_0.8.x1mm
L1: 3.3uH; L_Wuerth_MAPI-3015
L2: 2.2uH; L_Wuerth_MAPI-3015
L3: NR3015T100M; L_Wuerth_MAPI-3015
Q1, Q2: PMF250XNEX; SOT-323_SC-70
Q3, Q4: SSM6N35AFE; SOT-563
Q5: NX138BKWX; SOT-323_SC-70
R1: 6.8K; R_0402_1005Metric
R2: 53.6K; R_0402_1005Metric
R3: 22K; R_0402_1005Metric
R4: 47K; R_0402_1005Metric
R5: 100K; R_0402_1005Metric
R6, R7, R17, R18, R23, R24, R25, R26, R27, R28, R29: 10K; R_0402_1005Metric
R8, R11: 976K; R_0402_1005Metric
R9: 1K; R_0603_1608Metric
R10, R32: 2.2; R_0603_1608Metric
R12, R14: 150K; R_0402_1005Metric
R13: 10; R_0402_1005Metric
R15: 130K; R_0402_1005Metric
R16: 52.3K; R_0402_1005Metric
R19, R31: 470K; R_0402_1005Metric
R20, R21, R34, R35: 1K; R_0402_1005Metric
R22: 0.47R; R_0603_1608Metric
R30, R33: 100; R_0402_1005Metric
TP1, TP2, TP3, TP4, TP5, TP6, TP8: TestPoint; TestPoint_Pad_D1.0mm
U1: LMV7271; SOT-353_SC-70-5
U2: AP63200WU; TSOT-23-6
U3: TPS62171DSG; WSON-8-1EP_2x2mm_P0.5mm_EP0.9x1.6mm_ThermalVias
U4: APS6404L-SQN; SON-8-1EP_3x2mm_P0.5mm_EP1.4x1.6mm
U5: AT25XE321D-UUN-T; WLCSP 12-ball 3 x 2 x 3 Array
U6: EFM32PG23B200F512IM40; QFN-40_EP_5x5_Pitch0.4mm
U7: TXU0104PW; Texas_R-PUQFN-N12
Y1: FC2012AN; Crystal_SMD_2012-2Pin_2.0x1.2mm
Y2: 39MHz; Crystal_SMD_2016-4Pin_2.0x1.6mm
mouse-bite-2mm-slot, mouse-bite-2mm-slot#2, mouse-bite-2mm-slot#3: VAL**; mouse-bite-2mm_DEEP

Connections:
+1V8: C1.2, C28.2, C30.2, C32.1, C33.1, C34.2, C35.1, C36.1, C38.1, C41.2, D1.2 (K), FB1.1, FB3.2, J6.1, L2.2, R5.1, R18.2, R31.1, TP2.1, U3.6 (VOS), U4.8 (VCC), U5.B2 (VCC), U6.12 (DVDD), U6.32 (VREGVDD), U6.34 (DVDD), U6.36 (IOVDD), U7.1 (VCCA)
+2V8: C27.1, C29.2, C31.2, C42.1, C50.2, C57.1, FB4.2, J4.15, J4.16, J5.4, L1.2, R15.1, R24.2, R25.1, R26.1, R29.2, TP3.1, U7.11 (VCCB), U7.12 (OE)
/Display/2V8_EN: C46.1, Q3.2 (G), Q3.5 (G), R14.2, R20.2, R21.2, U2.2 (EN), U6.29 (PA09)
/Display/BUSY: R27.2, U6.15 (PB04)
/Display/E_BUSY: J4.9, R27.1
/Display/E_CS: U6.38 (PD02), U7.4 (A3)
/Display/E_D/C: U6.37 (PD03), U7.5 (A4)
/Display/E_MISO: R34.1, U5.D4 (IO1/SO), U6.2 (PC01)
/Display/E_RES: J4.10, Q4.6 (D), R24.1
/Display/E_SCK: U5.F2 (SCK), U6.4 (PC03), U7.3 (A2)
/Display/E_SDI: U5.E3 (SI/IO0), U6.3 (PC02), U7.2 (A1)
/Display/GDR: J4.2, Q2.1 (G), R19.1, R35.1
/Display/H_CS: J4.12, U7.8 (B3)
/Display/H_D/C: J4.11, U7.7 (B4)
/Display/H_SCK: J4.13, U7.9 (B2)
/Display/H_SDI: J4.14, R33.1, R34.2
/Display/INT: R28.2, U6.18 (PB01)
/Display/POW: C43.2, C44.1, FB4.1, L3.1
/Display/PREVGH: C48.1, D10.1 (K), J4.21, TP5.1
/Display/PREVGL: C47.1, D9.1, J4.23, TP4.1
/Display/RES: Q4.2 (G), R23.2, U6.26 (PA06)
/Display/RESE: J4.3, Q2.2 (S), R22.1
/Display/RES_TC: Q4.5 (G), R6.2, U6.27 (PA07)
/Display/SCL: Q3.3 (D), R21.1, U6.24 (PA04)
/Display/SDA: Q3.6 (D), R20.1, U6.25 (PA05)
/Display/T_INT: J5.2, R28.1
/Display/T_RES: J5.3, Q4.3 (D), R29.1
/Display/T_SCL: J5.5, Q3.4 (S), R26.2
/Display/T_SDA: J5.6, Q3.1 (S), R25.2
/Display/VCOM: C54.2, J4.24, TP6.1
/MCU/DATA: TP8.1, U1.4, U6.28 (PA08)
/MCU/FLASH_CS: U5.B4 (~CS), U6.1 (PC00)
/MCU/HV: C6.2, C8.2, C10.2, C11.2, C13.2, C15.2, C17.2, C19.2, C22.2, C23.1, C24.2, C25.1, C58.2, C59.2, C60.2, C61.2, C62.2, C63.2, C64.2, C65.2, C66.2, C67.2, C68.2, C69.2, C70.2, C71.2, C72.2, C73.2, C74.2, C75.2, C76.2, C77.2, C78.2, C79.2, C80.2, C81.2, C82.2, C83.2, C84.2, C85.2, C86.2, D3.1 (K), D7.1 (K), D12.2 (K1), D12.4 (K2), FB2.1, R11.1, U2.3 (IN), U3.2 (VIN), U3.3 (EN)
/MCU/P_GOOD: C40.1, J6.8, R18.1, U3.8 (PG), U6.11 (~RESET)
/MCU/P_IN: J6.6, R32.1
/MCU/RAM_CS: U4.1 (~CE), U6.5 (PC04)
/MCU/RX: J6.2, U6.14 (PB05)
/MCU/R_MISO: U4.2 (SO/SIO), U6.6 (PC05)
/MCU/R_MOSI: U4.5 (SI/SIO), U6.7 (PC06)
/MCU/R_SCK: U4.6 (SCLK), U6.8 (PC07)
/MCU/SWDCK: J6.7, U6.21 (PA01)
/MCU/SWDIO: J6.5, U6.22 (PA02)
/MCU/TX: J6.3, U6.13 (PB06)
/MCU/V_CHK: C20.1, R11.2, R12.1, U6.20 (PA00)
/MCU/~MCU_OK: C87.2, Q5.1 (G), R31.2, U6.23 (PA03)
/Power/CN: C6.1, C8.1, C10.1, C11.1, C13.1, C15.1, C17.1, C19.1, C81.1, JP1.1 (A), JP2.2 (B), JP3.2 (B), JP5.1 (A), JP6.2 (B), JP7.1 (A), JP8.2 (B), JP9.1 (A), Q1.3 (D)
/Power/IN_DT: C12.1, C14.1, C16.1, C18.1, JP10.2 (B), R1.1, R10.2, TP1.1
GND: C1.1, C2.2, C4.1, C5.1, C7.2, C9.2, C12.2, C14.2, C16.2, C20.2, C21.1, C22.1, C23.2, C24.1, C25.2, C28.1, C29.1, C30.1, C31.1, C32.2, C33.2, C34.1, C35.2, C36.2, C37.2, C38.2, C39.1, C40.2, C41.1, C42.2, C43.1, C44.2, C46.2, C47.2, C48.2, C49.1, C50.1, C51.1, C52.1, C53.1, C54.1, C55.1, C56.1, C57.2, C87.1, D1.1 (A), D5.2 (A), D9.2, J2.1, J4.8, J4.17, J4.S2 (S), J5.1, J5.S2 (S), J6.4, J8.1, JP3.1 (A), JP4.1 (A), Q1.2 (S), Q4.1 (S), Q4.4 (S), Q5.2 (S), R2.2, R6.1, R8.2, R9.1, R12.2, R14.1, R16.2, R17.2, R19.2, R22.2, R23.1, U1.2 (V-), U2.4 (GND), U3.1 (PGND), U3.4 (AGND), U3.5 (FB), U3.9 (PAD), U4.4 (VSS), U5.C3 (GND), U6.33 (VREGVSS), U6.41 (VSS), U7.6 (GND), Y2.2
unnamed: C3.1, R3.1, R4.2
unnamed: C21.2, D4.2, FB2.2
unnamed: C45.1, D9.3
unnamed: D1.3 (common), D2.2 (A), R1.2
unnamed: C2.1, C3.2, D2.1 (K), R2.1
unnamed: D3.2 (A), R7.1
unnamed: D5.1 (K), R13.2
unnamed: D7.2 (A), R17.1, R32.2
unnamed: D8.2 (A), Q5.3 (D)
unnamed: D8.1 (K), R30.2
unnamed: C45.2, D10.2 (A), L3.2, Q2.3 (D)
unnamed: D12.1 (A1), R13.1
unnamed: D12.3 (A2), R30.1
unnamed: C9.1, J1.1, R9.2, R10.1
unnamed: C49.2, J4.4
unnamed: C56.2, J4.5
unnamed: C51.2, J4.18
unnamed: C55.2, J4.19
unnamed: C52.2, J4.20
unnamed: C53.2, J4.22
unnamed: J7.1, U6.17 (PB02)
unnamed: J7.2, U6.16 (PB03)
unnamed: C58.1, C66.1, C74.1, C82.1, JP1.2 (B)
unnamed: C59.1, C67.1, C75.1, C83.1, JP2.1 (A)
unnamed: D4.1, JP4.2 (B)
unnamed: C60.1, C68.1, C76.1, C84.1, JP5.2 (B)
unnamed: C61.1, C69.1, C77.1, C85.1, JP6.1 (A)
unnamed: C62.1, C70.1, C78.1, C86.1, JP7.2 (B)
unnamed: C63.1, C65.1, C71.1, C79.1, JP8.1 (A)
unnamed: C64.1, C72.1, C73.1, C80.1, JP9.2 (B)
unnamed: C18.2, D4.3, JP10.1 (A)
unnamed: C7.1, Q1.1 (G), R7.2, R8.1
unnamed: R4.1, U1.1 (+)
unnamed: C4.2, R3.2, R5.2, U1.3 (-)
unnamed: C5.2, FB1.2, U1.5 (V+)
unnamed: C26.2, U2.6 (BST)
unnamed: C27.2, R15.2, R16.1, U2.1 (FB)
unnamed: C26.1, L1.1, U2.5 (SW)
unnamed: L2.1, U3.7 (SW)
unnamed: C37.1, FB3.1, U6.35 (AVDD)
unnamed: C39.2, U6.30 (CAP)
unnamed: U6.9 (HFXTAL_I), Y2.3
unnamed: U6.10 (HFXTAL_O), Y2.1
unnamed: R35.2, U6.19 (PB00)
unnamed: U6.40 (PD00), Y1.2
unnamed: U6.39 (PD01), Y1.1
unnamed: R33.2, U7.10 (B1)

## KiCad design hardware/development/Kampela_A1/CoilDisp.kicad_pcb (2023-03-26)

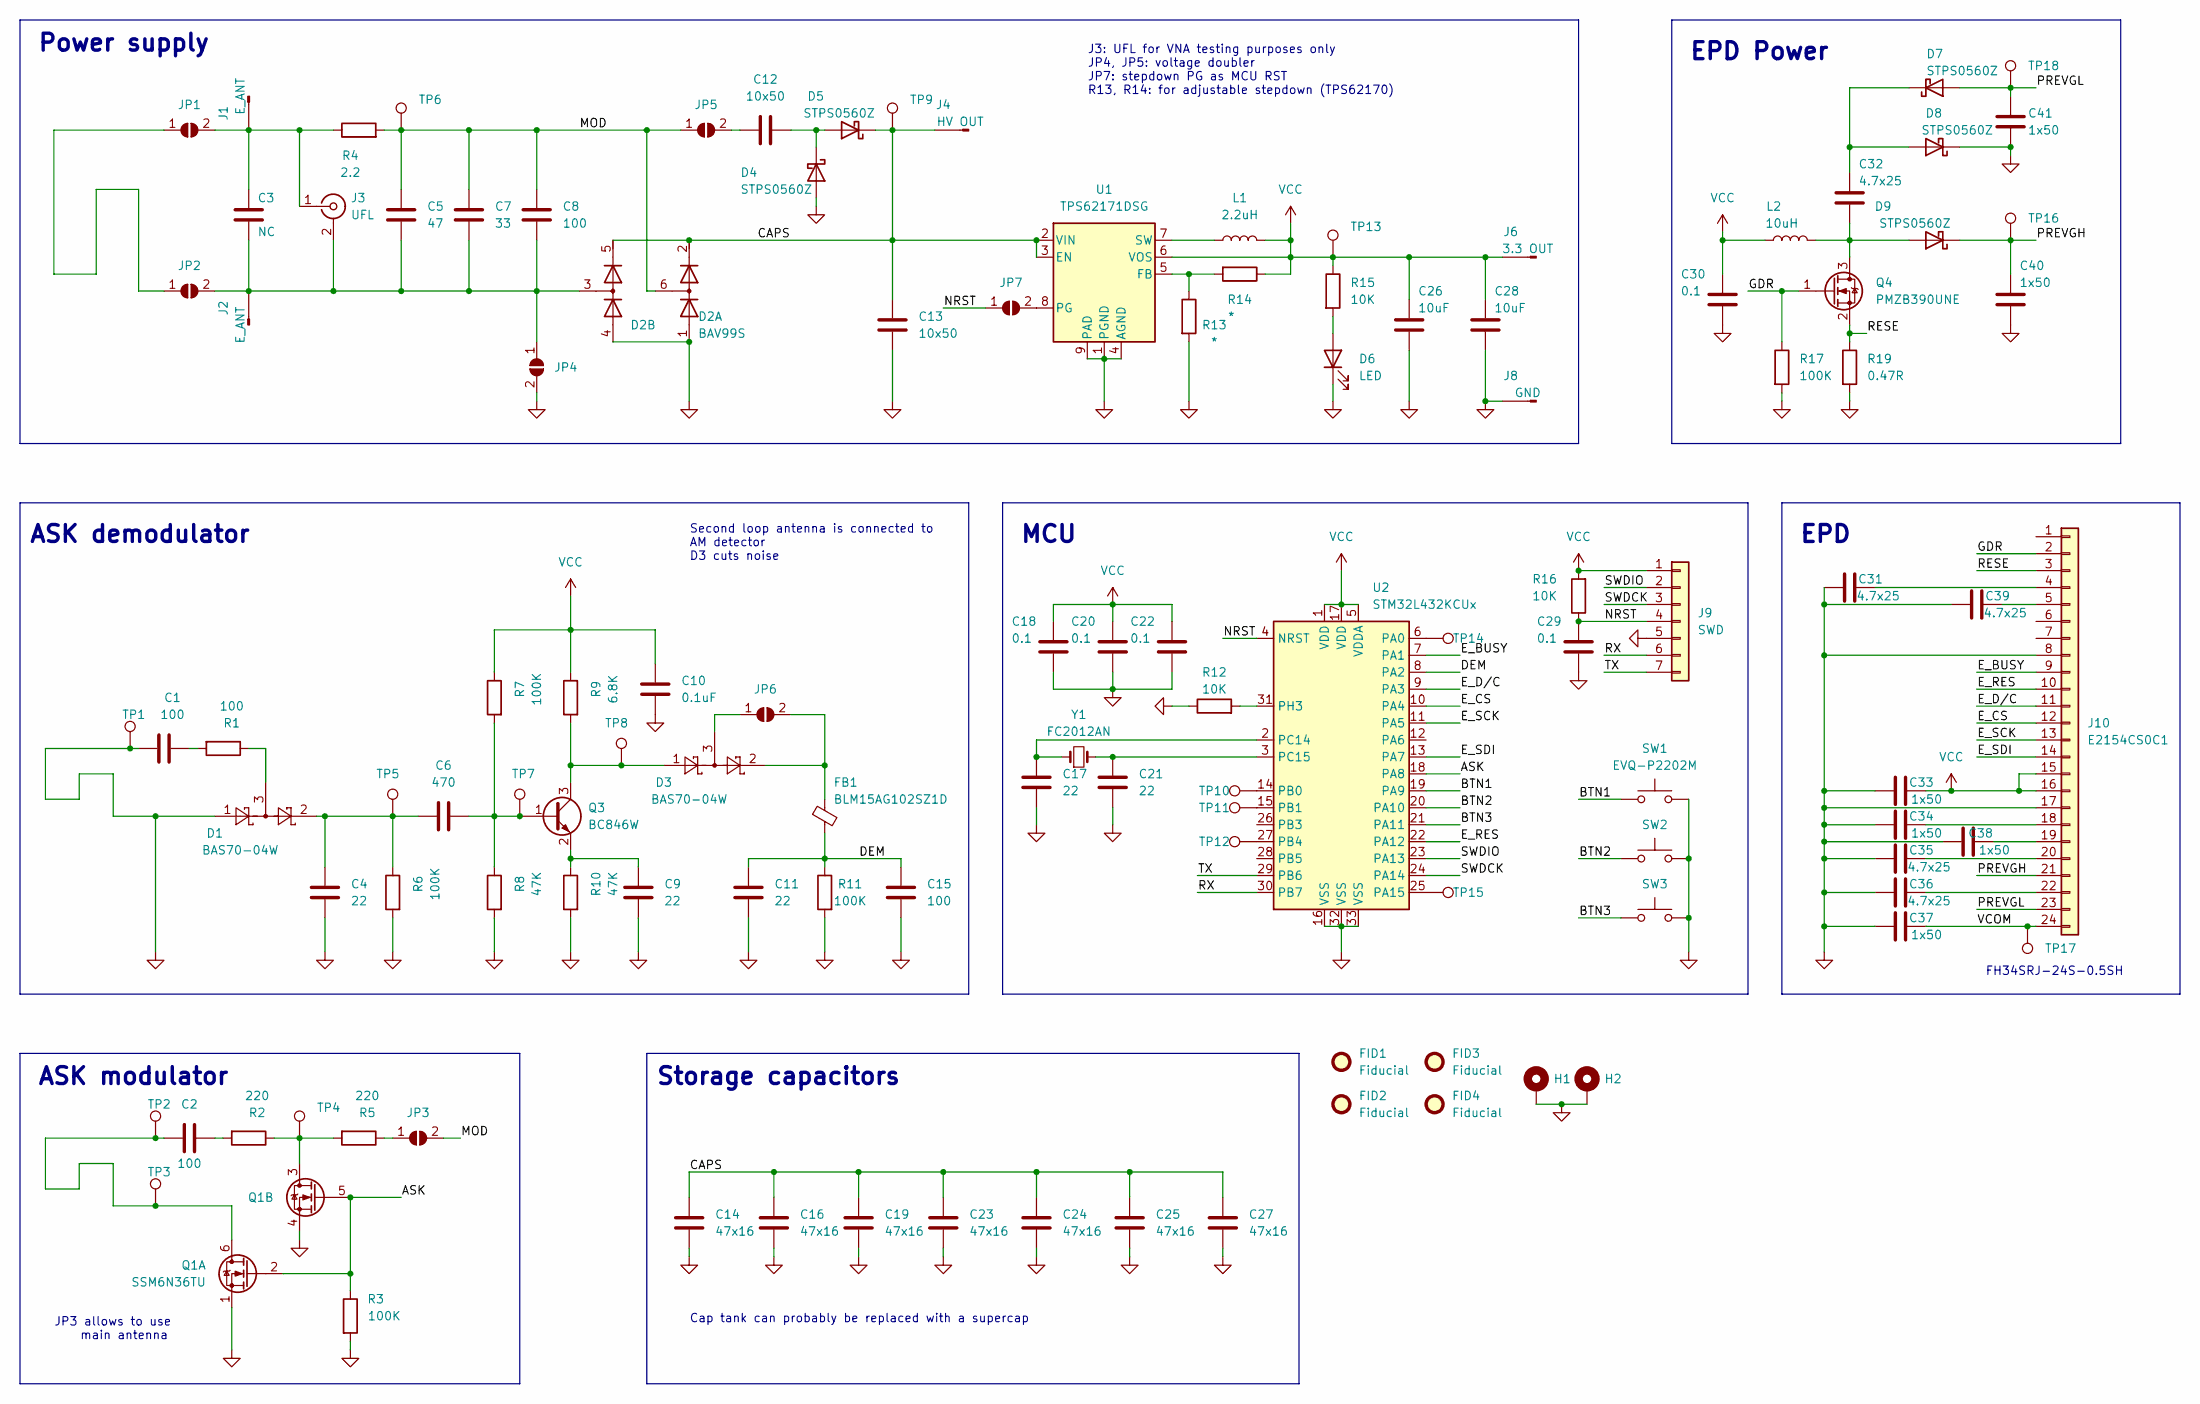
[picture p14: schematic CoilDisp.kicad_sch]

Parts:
C1, C2, C8: 100; C_0603_1608Metric
C3: NC; C_0603_1608Metric
C4, C9, C11, C17, C21: 22; C_0402_1005Metric
C5: 47; C_0603_1608Metric
C6: 470; C_0402_1005Metric
C7: 33; C_0603_1608Metric
C10: 0.1uF; C_0402_1005Metric
C12: 10x50; C_0603_1608Metric
C13: 10x50; C_1206_3216Metric
C14, C16, C19, C23, C24, C25, C27: 47x16; C_1210_3225Metric
C15: 100; C_0402_1005Metric
C18, C20, C22, C29, C30: 0.1; C_0402_1005Metric
C26, C28: 10uF; C_0603_1608Metric
C31, C32, C35, C36, C39: 4.7x25; C_0402_1005Metric
C33, C34, C37, C38, C40, C41: 1x50; C_0402_1005Metric
D1, D3: BAS70-04W; SOT-323_SC-70
D2: BAV99S; SOT-563
D4, D5, D7, D8, D9: STPS0560Z; D_SOD-123F
D6: LED; LED_0603_1608Metric
FB1: BLM15AG102SZ1D; L_0402_1005Metric
FID1, FID2, FID3, FID4: Fiducial; Fiducial_0.5mm_Mask1.5mm
H1, H2: MountingHole_Pad; MountingHole_3.2mm_M3_DIN965_Pad_TopBottom
J1, J2: E_ANT; TestPoint_THTPad_D1.0mm_Drill0.5mm
J3: UFL; U.FL_Hirose_U.FL-R-SMT-1_Vertical
J4: HV OUT; TestPoint_THTPad_D1.0mm_Drill0.5mm
J6: 3.3 OUT; TestPoint_THTPad_D1.0mm_Drill0.5mm
J8: GND; TestPoint_THTPad_D1.0mm_Drill0.5mm
J9: SWD; PinHeader_1x07_P2.54mm_Vertical
J10: E2154CS0C1; HRS_FH34SRJ-24S-0.5SH(99)
JP1, JP2, JP3, JP4, JP5, JP6, JP7: SolderJumper_2_Open; SolderJumper-2_P1.3mm_Open_RoundedPad1.0x1.5mm
L1: 2.2uH; L_Wuerth_MAPI-3015
L2: 10uH; L_Vishay_IHLP-2020
Q1: SSM6N36TU; SOT-363_SC-70-6
Q3: BC846W; SOT-323_SC-70
Q4: PMZB390UNE; Diodes_DFN1006-3
R1: 100; R_0402_1005Metric
R2, R5: 220; R_0603_1608Metric
R3, R6, R7, R11, R17: 100K; R_0402_1005Metric
R4: 2.2; R_0603_1608Metric
R8, R10: 47K; R_0402_1005Metric
R9: 6.8K; R_0402_1005Metric
R12, R15, R16: 10K; R_0402_1005Metric
R13, R14: *; R_0603_1608Metric
R19: 0.47R; R_0603_1608Metric
SW1, SW2, SW3: EVQ-P2202M
TP1, TP2, TP3, TP4, TP5, TP6, TP7, TP8, TP9, TP10, TP11, TP12, TP13, TP14, TP15, TP16, TP17, TP18: TestPoint; TestPoint_Pad_D1.0mm
U1: TPS62171DSG; WSON-8-1EP_2x2mm_P0.5mm_EP0.9x1.6mm_ThermalVias
U2: STM32L432KCUx; QFN-32-1EP_5x5mm_P0.5mm_EP3.45x3.45mm
Y1: FC2012AN; Crystal_SMD_2012-2Pin_2.0x1.2mm

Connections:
/ASK: Q1.2 (G), Q1.5 (G), R3.1, U2.18 (PA8)
/BTN1: SW1.1, U2.19 (PA9)
/BTN2: SW2.1, U2.20 (PA10)
/BTN3: SW3.1, U2.21 (PA11)
/CAPS: C13.2, C14.2, C16.2, C19.2, C23.2, C24.2, C25.2, C27.2, D2.2 (K2), D2.5 (K4), D5.1 (K), J4.1, TP9.1, U1.2 (VIN), U1.3 (EN)
/DEM: C11.2, C15.2, FB1.2, R11.1, U2.8 (PA2)
/E_BUSY: J10.9, U2.7 (PA1)
/E_CS: J10.12, U2.10 (PA4)
/E_D/C: J10.11, U2.9 (PA3)
/E_RES: J10.10, U2.22 (PA12)
/E_SCK: J10.13, U2.11 (PA5)
/E_SDI: J10.14, U2.13 (PA7)
/GDR: J10.2, Q4.1 (G), R17.1
/MOD: C5.1, C7.1, C8.1, D2.6 (K3A4), JP3.2 (B), JP5.1 (A), R4.2, TP6.1; also elsewhere on the board
/NRST: C29.1, J9.4, JP7.1 (A), R16.1, U2.4 (NRST)
/PREVGH: C40.1, D9.1 (K), J10.21, TP16.1; also elsewhere on the board
/PREVGL: C41.1, D7.2 (A), J10.23, TP18.1; also elsewhere on the board
/RESE: J10.3, Q4.2 (S), R19.1
/RX: J9.6, U2.30 (PB7)
/SWDCK: J9.3, U2.24 (PA14)
/SWDIO: J9.2, U2.23 (PA13)
/TX: J9.7, U2.29 (PB6)
/VCOM: C37.2, J10.24, TP17.1; also elsewhere on the board
GND: C1.1, C4.2, C9.1, C10.1, C11.1, C13.1, C14.1, C15.1, C16.1, C17.1, C18.2, C19.1, C20.2, C21.1, C22.2, C23.1, C24.1, C25.1, C26.2, C27.1, C28.2, C29.2, C30.2, C31.1, C33.1, C34.1, C35.1, C36.1, C37.1, C38.1, C39.1, C40.2, C41.2, D1.1, D2.1 (A1), D2.4 (A3), D4.2 (A), D6.1 (K), D8.1 (K), H1.1, H2.1, J8.1, J9.5, J10.8, J10.17, JP4.2 (B), Q1.1 (S), Q1.4 (S), R3.2, R6.2, R8.2, R10.2, R11.2, R12.1, R13.2, R17.2, R19.2, SW1.2, SW2.2, SW3.2, TP1.1, U1.1 (PGND), U1.4 (AGND), U1.9 (PAD), U2.16 (VSS), U2.32 (VSS), U2.33 (VSS)
unnamed: C1.2, R1.2
unnamed: C2.1, Q1.6 (D), TP2.1, TP3.1
unnamed: C2.2, R2.2
unnamed: C3.1, J1.1, J3.1 (In), JP1.2 (B), R4.1
unnamed: C3.2, C5.2, C7.2, C8.2, D2.3 (K1A2), J2.1, J3.2 (Ext), JP2.2 (B), JP4.1 (A)
unnamed: C4.1, C6.1, D1.2, R6.1, TP5.1
unnamed: C6.2, Q3.1 (B), R7.2, R8.1, TP7.1
unnamed: C9.2, Q3.2 (E), R10.1
unnamed: C12.1, D4.1 (K), D5.2 (A)
unnamed: C12.2, JP5.2 (B)
unnamed: C17.2, U2.2 (PC14), Y1.1
unnamed: C21.2, U2.3 (PC15), Y1.2
unnamed: C31.2, J10.4
unnamed: C32.1, D7.1 (K), D8.2 (A)
unnamed: C32.2, D9.2 (A), L2.2, Q4.3 (D)
unnamed: C34.2, J10.18
unnamed: C35.2, J10.20
unnamed: C36.2, J10.22
unnamed: C38.2, J10.19
unnamed: C39.2, J10.5
unnamed: D1.3, R1.1
unnamed: D3.1, Q3.3 (C), R9.2, TP8.1
unnamed: D3.2, FB1.1, JP6.2 (B)
unnamed: D3.3, JP6.1 (A)
unnamed: D6.2 (A), R15.2
unnamed: JP1.1 (A), JP2.1 (A)
unnamed: JP3.1 (A), R5.1
unnamed: JP7.2 (B), U1.8 (PG)
unnamed: L1.1, U1.7 (SW)
unnamed: Q1.3 (D), R2.1, R5.2, TP4.1
unnamed: R12.2, U2.31 (PH3)
unnamed: R13.1, R14.2, U1.5 (FB)
unnamed 56: TP10.1, U2.14 (PB0); also elsewhere on the board
unnamed 57: TP11.1, U2.15 (PB1); also elsewhere on the board
unnamed 58: TP12.1, U2.27 (PB4); also elsewhere on the board
unnamed 59: TP14.1, U2.6 (PA0); also elsewhere on the board
unnamed 60: TP15.1, U2.25 (PA15); also elsewhere on the board
VCC: C10.2, C18.1, C20.1, C22.1, C26.1, C28.1, C30.1, C33.2, J6.1, J9.1, J10.15, J10.16, L1.2, L2.1, R7.1, R9.1, R14.1, R15.1, R16.2, TP13.1, U1.6 (VOS), U2.1 (VDD), U2.5 (VDDA), U2.17 (VDD)

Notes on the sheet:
ASK modulator
MCU
Power supply
EPD
Storage capacitors
FH34SRJ-24S-0.5SH
Second loop antenna is connected to AM detector D3 cuts noise
J3: UFL for VNA testing purposes only JP4, JP5: voltage doubler JP7: stepdown PG as MCU RST R13, R14: for adjustable stepdown (TPS62170)
ASK demodulator
Cap tank can probably be replaced with a supercap
JP3 allows to use main antenna
EPD Power

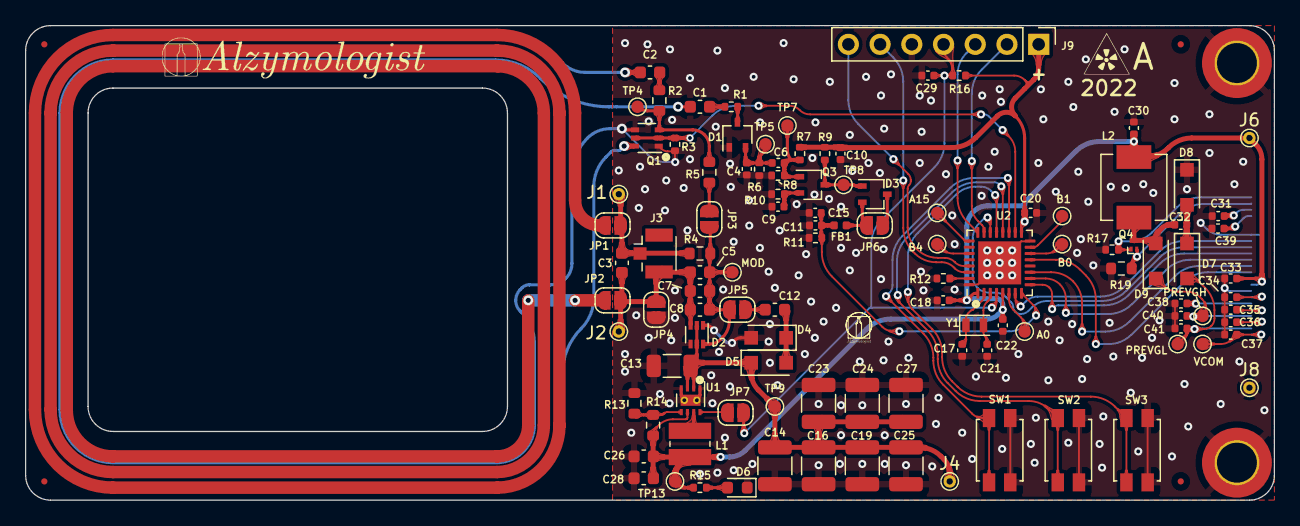
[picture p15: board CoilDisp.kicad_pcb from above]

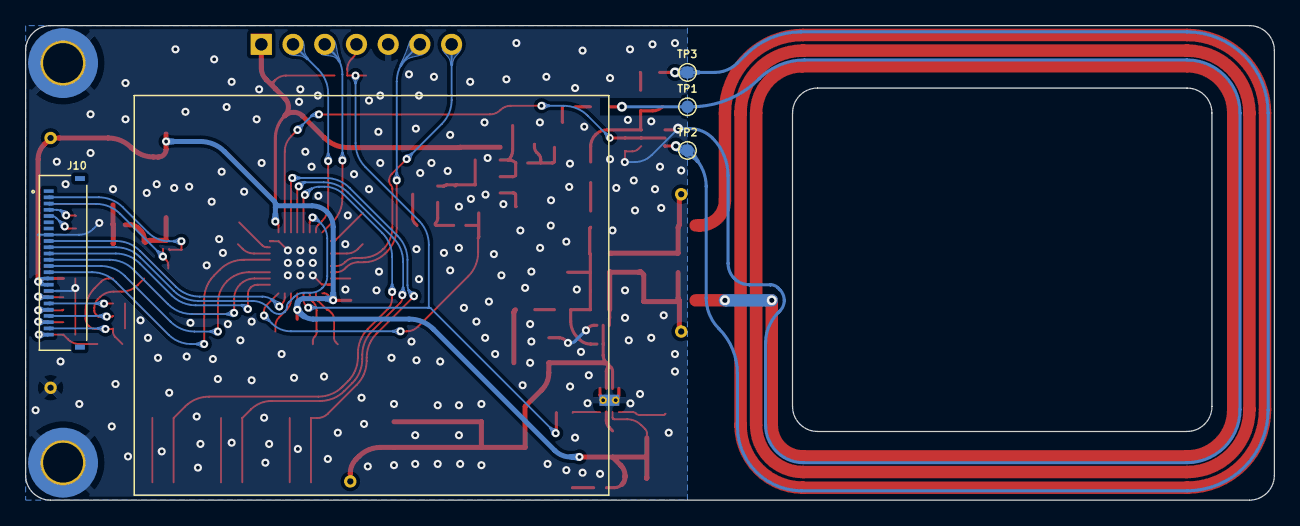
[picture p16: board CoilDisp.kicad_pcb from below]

Board: 2 copper layers, 100.0 x 38.0 mm, 119 parts (4 on the bottom side), 62 nets.

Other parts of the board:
A0, A15: TestPoint; TestPoint_Pad_D1.0mm
B0, B1, B4: TestPoint; TestPoint_Pad_D1.0mm
MOD: TestPoint; TestPoint_Pad_D1.0mm
PREVGH: TestPoint; TestPoint_Pad_D1.0mm
PREVGL: TestPoint; TestPoint_Pad_D1.0mm
VCOM: TestPoint; TestPoint_Pad_D1.0mm

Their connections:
/MOD: MOD.1; also elsewhere on the board
/PREVGH: PREVGH.1; also elsewhere on the board
/PREVGL: PREVGL.1; also elsewhere on the board
/VCOM: VCOM.1; also elsewhere on the board
unnamed 56: B0.1; also elsewhere on the board
unnamed 57: B1.1; also elsewhere on the board
unnamed 58: B4.1; also elsewhere on the board
unnamed 59: A0.1; also elsewhere on the board
unnamed 60: A15.1; also elsewhere on the board

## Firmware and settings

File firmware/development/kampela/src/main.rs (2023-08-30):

#![no_main]
#![no_std]
#![feature(alloc_error_handler)]

extern crate alloc;
extern crate core;

use alloc::{format, string::{String, ToString}, vec::Vec};
use core::{alloc::Layout, panic::PanicInfo};
use core::ptr::addr_of;
use cortex_m::asm::delay;
use cortex_m_rt::{entry, exception, ExceptionFrame};
use embedded_alloc::Heap;
use lazy_static::lazy_static;
use parity_scale_codec::Decode;
use primitive_types::H256;

use efm32pg23_fix::{interrupt, Interrupt, NVIC, Peripherals};

mod ui;
use ui::UI;
mod nfc;
use nfc::{BufferStatus, turn_nfc_collector_correctly, NfcCollector, process_nfc_payload};

#[global_allocator]
static HEAP: Heap = Heap::empty();

use kampela_system::{
    PERIPHERALS, CORE_PERIPHERALS, in_free,
    devices::{power::ADC, psram::{psram_read_at_address, CheckedMetadataMetal, ExternalPsram, PsramAccess}, se_rng::SeRng},
    draw::burning_tank, 
    init::init_peripherals,
    parallel::Operation,
    BUF_QUARTER, CH_TIM0, LINK_1, LINK_2, LINK_DESCRIPTORS, TIMER0_CC0_ICF, NfcXfer, NfcXferBlock,
};

use core::cell::RefCell;
use core::ops::DerefMut;
use cortex_m::interrupt::free;
use cortex_m::interrupt::Mutex;

//use p256::ecdsa::{signature::{hazmat::PrehashVerifier}, Signature, VerifyingKey};
//use sha2::Digest;
//use spki::DecodePublicKey;
use substrate_parser::{MarkedData, ShortSpecs, compacts::find_compact, parse_transaction};
use schnorrkel::{
    context::attach_rng,
    keys::Keypair,
    signing_context,
};

lazy_static!{
    #[derive(Debug)]
    static ref BUFFER_STATUS: Mutex<RefCell<BufferStatus>> = Mutex::new(RefCell::new(BufferStatus::new()));
}

/*
static mut GPIO_ODD_INT: bool = false;
static mut COUNT_ODD: bool = false;
static mut GPIO_EVEN_INT: bool = false;
static mut COUNT_EVEN: bool = false;
static mut READER: Option<[u8;5]> = None;
*/

#[alloc_error_handler]
fn oom(l: Layout) -> ! {
    panic!("out of memory: {:?}, heap used: {}, free: {}", l, HEAP.used(), HEAP.free());
}

#[panic_handler]
fn panic(panic: &PanicInfo<'_>) -> ! {
    let mut peripherals = unsafe{Peripherals::steal()};
    burning_tank(&mut peripherals, format!("{:?}", panic));
    loop {}
}

#[exception]
unsafe fn HardFault(exception_frame: &ExceptionFrame) -> ! {
    panic!("hard fault: {:?}", exception_frame)
}

#[interrupt]
fn LDMA() {
    free(|cs| {
        if let Some(ref mut peripherals) = PERIPHERALS.borrow(cs).borrow_mut().deref_mut() {
            peripherals.LDMA_S.if_.reset();
            let mut buffer_status = BUFFER_STATUS.borrow(cs).borrow_mut();
            match buffer_status.pass_if_done7() {
                Ok(_) => {
                    if !buffer_status.is_write_halted() {
                        peripherals.LDMA_S.linkload.write(|w_reg| w_reg.linkload().variant(1 << CH_TIM0));
                    }
                },
                Err(_) => {}
            }
        }
        else {panic!("can not borrow peripherals in ldma interrupt")}
    });
}

const ALICE_KAMPELA_KEY: &[u8] = &[24, 79, 109, 158, 13, 45, 121, 126, 185, 49, 212, 255, 134, 18, 243, 96, 119, 210, 175, 115, 48, 181, 19, 238, 61, 135, 28, 186, 185, 31, 59, 9, 172, 24, 200, 176, 25, 207, 214, 199, 221, 214, 171, 143, 80, 246, 86, 104, 48, 40, 21, 99, 114, 3, 232, 85, 101, 7, 128, 198, 36, 11, 101, 63, 180, 120, 97, 66, 191, 43, 74, 35, 69, 3, 219, 194, 72, 141, 68, 185, 188, 177, 117, 246, 178, 250, 89, 134, 116, 20, 248, 247, 151, 45, 130, 59];
const SIGNING_CTX: &[u8] = b"substrate";

#[entry]
fn main() -> ! {
    {
        use core::mem::MaybeUninit;
        const HEAP_SIZE: usize = 0x4600;
        static mut HEAP_MEM: [MaybeUninit<u8>; HEAP_SIZE] = [MaybeUninit::uninit(); HEAP_SIZE];
        unsafe { HEAP.init(HEAP_MEM.as_ptr() as usize, HEAP_SIZE) }
    }

    let westend_specs = ShortSpecs {
        base58prefix: 42,
        decimals: 12,
        name: "westend".to_string(),
        unit: "WND".to_string(),
    };

    let nfc_buffer: [u16; 4*BUF_QUARTER] = [1; 4*BUF_QUARTER];
    let nfc_transfer_block = NfcXferBlock {
        block0: NfcXfer {
            descriptors: LINK_DESCRIPTORS,
            source: TIMER0_CC0_ICF,
            dest: addr_of!(nfc_buffer[0]) as u32,
            link: LINK_1,
        },
        block1: NfcXfer {
            descriptors: LINK_DESCRIPTORS,
            source: TIMER0_CC0_ICF,
            dest: addr_of!(nfc_buffer[BUF_QUARTER]) as u32,
            link: LINK_1,
        },
        block2: NfcXfer {
            descriptors: LINK_DESCRIPTORS,
            source: TIMER0_CC0_ICF,
            dest: addr_of!(nfc_buffer[2*BUF_QUARTER]) as u32,
            link: LINK_1,
        },
        block3: NfcXfer {
            descriptors: LINK_DESCRIPTORS,
            source: TIMER0_CC0_ICF,
            dest: addr_of!(nfc_buffer[3*BUF_QUARTER]) as u32,
            link: LINK_2,
        },
    };

    let mut peripherals = Peripherals::take().unwrap();

    init_peripherals(&mut peripherals, addr_of!(nfc_transfer_block));

    delay(1000);

    free(|cs| {
        let mut core_periph = CORE_PERIPHERALS.borrow(cs).borrow_mut();
        NVIC::unpend(Interrupt::LDMA);
        NVIC::mask(Interrupt::LDMA);
        unsafe {
            core_periph.NVIC.set_priority(Interrupt::LDMA, 3);
            NVIC::unmask(Interrupt::LDMA);
        }
    });

    delay(1000);


    free(|cs| {
        PERIPHERALS.borrow(cs).replace(Some(peripherals));
    });

    let pair_derived = Keypair::from_bytes(ALICE_KAMPELA_KEY).unwrap();

//    let mut touch_data = [0; LEN_NUM_TOUCHES];
//    let mut touched = false;

    let mut nfc_collector = NfcCollector::new();

    let mut ui = UI::init();
    let mut adc = ADC::new();

    let mut got_transaction = None;

    loop {
        adc.advance(());
        ui.advance(adc.read());
        
        turn_nfc_collector_correctly(&mut nfc_collector, &nfc_buffer);

        if let NfcCollector::Done(ref a) = nfc_collector {
            NVIC::mask(Interrupt::LDMA);

            let nfc_payload = process_nfc_payload(a).unwrap();

            let mut first_byte: Option<u8> = None;
            in_free(|peripherals| {
                first_byte = Some(psram_read_at_address(peripherals, nfc_payload.encoded_data.start_address, 1usize).unwrap()[0]);
            });
            
/* // calculate correct hash of the payload
{
            let mut hasher = sha2::Sha256::new();
            in_free(|peripherals| {
                for shift in 0..nfc_payload.encoded_data.total_len {
                    let address = nfc_payload.encoded_data.start_address.try_shift(shift).unwrap();
                    let single_element_vec = psram_read_at_address(peripherals, address, 1usize).unwrap();
                    if shift == 0 {first_byte = Some(single_element_vec[0])}
                    hasher.update(&single_element_vec);
                }
            });
            let hash = hasher.finalize();
            
            // transform signature and verifying key from der-encoding into usable form
            let signature = Signature::from_der(&nfc_payload.companion_signature).unwrap();
            let verifying_key = VerifyingKey::from_public_key_der(&nfc_payload.companion_public_key).unwrap();

            // and check
            assert!(verifying_key
                .verify_prehash(&hash, &signature)
                .is_ok());

}
*/

            if let Some(3) = first_byte {
                // got signable transaction
                // panic!("got signable transaction");
                let mut genesis_hash_bytes_option = None;
                in_free(|peripherals| {
                    let address = nfc_payload.encoded_data.start_address.try_shift(1usize).unwrap();
                    genesis_hash_bytes_option = Some(psram_read_at_address(peripherals, address, 32usize).unwrap());
                });
                let genesis_hash = H256(genesis_hash_bytes_option.unwrap().try_into().expect("static size"));
                
                let mut metadata_psram_access_option = None;
                let mut position = 1usize + 32usize;
                in_free(|peripherals| {
                    let mut external_psram = ExternalPsram{peripherals};
                    let compact_meta = find_compact::<u32, PsramAccess, ExternalPsram>(&nfc_payload.encoded_data, &mut external_psram, position).unwrap();
                    let start_address = nfc_payload.encoded_data.start_address.try_shift(compact_meta.start_next_unit).unwrap();
                    metadata_psram_access_option = Some(PsramAccess{start_address, total_len: compact_meta.compact as usize});
                    position = compact_meta.start_next_unit + compact_meta.compact as usize;
                });
                let metadata_psram_access = metadata_psram_access_option.unwrap();
                
                let mut checked_metadata_metal_option = None;
                in_free(|peripherals| {
                    let mut external_psram = ExternalPsram{peripherals};
                    checked_metadata_metal_option = Some(CheckedMetadataMetal::from(&metadata_psram_access, &mut external_psram).unwrap());
                });
                let checked_metadata_metal = checked_metadata_metal_option.unwrap();
                
                let mut signable_transaction_option = None;
                in_free(|peripherals| {
                    let mut external_psram = ExternalPsram{peripherals};
                    let compact_transaction = find_compact::<u32, PsramAccess, ExternalPsram>(&nfc_payload.encoded_data, &mut external_psram, position).unwrap();
                    let start_address = nfc_payload.encoded_data.start_address.try_shift(compact_transaction.start_next_unit).unwrap();
                    let transaction_encoded = psram_read_at_address(peripherals, start_address, compact_transaction.compact as usize).unwrap();
                    signable_transaction_option = Some(Vec::<u8>::decode(&mut &transaction_encoded[..]).unwrap());
                    position = compact_transaction.start_next_unit + compact_transaction.compact as usize;
                });
                let signable_transaction = signable_transaction_option.unwrap();
                
                in_free(|peripherals| {
                    let start_address = nfc_payload.encoded_data.start_address.try_shift(position).unwrap();
                    let public_key = psram_read_at_address(peripherals, start_address, 33usize).unwrap();
                    assert!(public_key.starts_with(&[1u8]) & (public_key[1..] == ALICE_KAMPELA_KEY[64..]), "Unknown address.");
                });
                
                in_free(|peripherals| {
                    let mut external_psram = ExternalPsram{peripherals};
                    let binding = signable_transaction.as_ref();
                    let marked_data: MarkedData<'_, &[u8], ()> = MarkedData::mark(&binding, &mut ()).unwrap();
                    let data_to_sign = binding[marked_data.call_start()..].to_vec();
                    let decoded_transaction = parse_transaction(
                        &signable_transaction.as_ref(),
                        &mut external_psram,
                        &checked_metadata_metal,
                        genesis_hash
                    ).unwrap();
                    let carded = decoded_transaction.card(&westend_specs);
                    got_transaction = Some((
                        carded.call_result.unwrap().iter().map(|card| card.show()).collect::<Vec<String>>().join("\n"),
                        carded.extensions.iter().map(|card| card.show()).collect::<Vec<String>>().join("\n"),
                        data_to_sign
                    ));
                });
            }
            else {nfc_collector = NfcCollector::new();}
        }
        if got_transaction.is_some() {break}
    }
    let transaction = got_transaction.unwrap();
    let context = signing_context(SIGNING_CTX);
    let signature = pair_derived.sign(attach_rng(context.bytes(&transaction.2), &mut SeRng{}));
    let mut signature_with_id: [u8; 65] = [1; 65];
    signature_with_id[1..].copy_from_slice(&signature.to_bytes());
    let signature_into_qr: [u8; 130] = hex::encode(signature_with_id).into_bytes().try_into().expect("static known length");

    ui.handle_rx(transaction.0, transaction.1, signature_into_qr);

    loop {
        adc.advance(());
        ui.advance(adc.read());
    }
}

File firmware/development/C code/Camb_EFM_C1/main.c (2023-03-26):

#include <em_chip.h>
#include <em_cmu.h>
#include <em_core.h>
#include <em_timer.h>




#include "main.h"

#include "utils.h" 

#include "epd27.h"
#include "FT6336.h"
#include "em_ldma.h"

#include "dmadrv.h" 
#include "config\dmadrv_config.h"

#include "AT25.h"
#include "psram.h"

#include "NfcDecoder.h"
#include "sl_status.h"
#include <math.h>
#include "alzlogo.h"
#include "em_acmp.h"


#define SHOWPACK



uint8_t FlashtoEpd[1024];
uint16_t FlashEpdP;
uint32_t FBp;
uint32_t PicBase;

#define LDMA_CH_MASK        (1 << 0)
unsigned int channelRX;
uint8_t PrintPos = 0;
uint8_t AddDataPos = 0;
bool PackLoaded = false;
uint16_t PsramPage;


//char PrintBuf[256];

uint8_t cnnt = 0;

char PassEntered[16];
uint8_t PassLen = 0;

char TcVal[4][4] =
{
	'7', '8', '9', 'F',
	'4', '5', '6', 'E',
	'1', '2', '3', 'D',
	'0', 'A', 'B', 'C'
};

char PassIs[] = { "EDB0C9" };


char ch[16];
bool PassOk = false;



extern volatile double MainVoltage;
extern bool AllPacksReceived;


bool PowerState = false;

char ReceivedChar;

char EpdPrint[128];


extern uint8_t NfcData[NFC_DECODED_MAX]; 
size_t NfcDataLen;


#define RX_BUFFER_SIZE      1024 /* Even numbers only */

/* RX Ring Buffer */
struct 
{
	char buffer[RX_BUFFER_SIZE];
	int startIndex;
	int stopIndex; 
	int counts; 
} rxBuffer = { .startIndex = 0, .stopIndex = 0 };


//Touch
bool TouchFound;
uint8_t TouchModel;
bool Touched;
uint16_t TouchX;
uint16_t TouchY;
uint8_t TouchArr[8];


//touch panel int
void IntWork()
{
	uint32_t intval = GPIO_IntGet();

	if (PowerState)
	{

		switch (intval)
		{

		case 1 << INT_PIN: //touch
		
			if (FT6336_ReadLocation(TouchArr))
			{
				if (!Touched)
				{
					Touched = true;
					TouchX = TouchArr[0];
					TouchY = (TouchArr[1] << 8) + TouchArr[2];
					
					
				}
			}
						
			break;

	
		default:
			break;
		}
	}
	
	GPIO_IntClear(intval);

}



void GPIO_EVEN_IRQHandler(void) 
{
	IntWork();
}



void GPIO_ODD_IRQHandler(void) 
{
	IntWork(); 
}




/******************************/
/******************************/
/******************************/
/******************************/
/******************************/
/******************************/
/******************************/
/******************************/
/******************************/
/******************************/
/******************************/
/******************************/
/******************************/
/******************************/
/******************************/
/******************************/
/******************************/
/******************************/
/******************************/
/******************************/
/******************************/
/******************************/
/******************************/
/******************************/
/******************************/
/******************************/
/******************************/
/******************************/



void dispw(uint8_t d)
{
	
	cnnt++;
	if (cnnt < 23)
	{
		
		FlashtoEpd[FlashEpdP++] = d;
		if (FlashEpdP > 255)
		{
			FlashEpdP = 0;
			while (SpiFlashReadStatus() & SPI_STATUS_BSY) ; //wait for ready 
			SpiFlashCmd(SPICMD_WREN);
			SpiFlashErasePage(FBp); //erase page

			while (SpiFlashReadStatus() & SPI_STATUS_BSY) ; //wait for ready 
			SpiFlashCmd(SPICMD_WREN);
			SpiFlashWritePage(FlashtoEpd, FBp);
			FBp += 0x100;
		}
	}
	if (cnnt > 49) cnnt = 0;

}




void ShowButtons()
{
	const uint16_t Ys = 88;
	uint8_t i, x, y;
	char ch[2] = { 0, 0 };	
	
	for (i = 0; i < 176; i += 44)
	{
		EPD_line(i, 0 + Ys, i, 175 + Ys, 1);
		EPD_line(0, i + Ys, 175, i + Ys, 1);
	}
	EPD_line(175, 0 + Ys, 175, 175 + Ys, 1);
	EPD_line(0, 175 + Ys, 175, 175 + Ys, 1);

	for (y = 0; y < 4; y++)
	{
		for (x = 0; x < 4; x++)
		{
			ch[0] = TcVal[y][x];
			EPD_Text(x * 44 + 16, y * 44 + 15 + Ys, ch, 1, 0);

		}
	}
		
	EPD_PartWriteFull();
}












void Shuffle(char * arr)
{
	uint8_t RandV;
	char bc, idx;
	for (uint8_t i = 0; i < 16; i++)
	{
		RandV = EfmGetRandom();
		idx = RandV & 0x04;
		bc = arr[i];
		arr[i] = arr[idx];
		arr[idx] = bc;
	}
}





int main()
{
	uint8_t i, j;
	
	uint16_t x, y;
	float mfX, mfY;
	float xScreen, yScreen;
	float xCent, yCent;
	
	void *user;
	Ecode_t res; 

	CHIP_Init();
	ClockInit();
	
#ifndef SHOWPACK
	
	while (true)
	{
		// Enter EM2 sleep, woken by IADC interrupt
		EMU_EnterEM2(true);
		if (MainVoltage > 14.0f) break;
	}
#endif	

	
	
	SpiFlashDispInit(); //flash and disp SPI init
	SpiFlashUDPD(); //Ultra-Deep Power-Down of Flash chip

	DMADRV_Init(); //init DMA
	
	SpiDispInit(); //touch panel and disp lines init

	UartInit();
	PsramInit(); //Psram ports init	
	
	NfcInit();
	
	

	
	
	POW_2V8(1); // enable 2.8 volt
	POW_I2C_T(1); // enable i2c level translator
	PowerState = true;

	Delay(1000);
	
	
	uint16_t Fs = SYSTEM_GetFlashSize();
	uint8_t rev = SYSTEM_GetDevinfoRev();
	uint16_t Pn = SYSTEM_GetPartNumber();

	uPrintf("\r\nReady  Pn: %u, Rev: %u, Flash: %u\r\n", Pn, rev, Fs);
	
	EPD_SetRotate(0);
	EPD_HW_Init(); //Electronic paper initialization	
	EPD_WhiteScreen_White();
	EPD_clear(1); //buf init
	EPD_DeepSleep(); //EPD_DeepSleep
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

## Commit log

2022-09-20 feat: Siltti - Kampela companion demo app (#3)
    * feat: android app outline
    * chore: move companion rust code to appropriate place
    * feat: parse QR codes in the app
    * style: visible frame counter
    * feat: 3 minimal states of the app
2022-09-29 fix: pass uniffi callback interface into Kotlin (#8)
    * fix: uniffi wants error not to be called error
    * feat: pass stub-signed qr info into TX initiating closure
    [process_input.rs]
2022-10-12 NFC power supply
2022-10-12 Devices list
2022-10-18 feat: companion signing for all transmittables (#9)
    * feat: companion signing for all transmittables
    * chore: more intuitive naming
    * chore: fmt
    * fix: rename things on Kotlin side
    * fix: correct meta prefix
    * feat: sign NFC payload in kompanion
    * chore: remove obsolete errors
    * fix: proper payload prefix removal
    [process_input.rs]
2022-10-31 feat: detect and send NFC fountain (#16)
    * feat: detect and send NFC fountain
    * fix: network specs parsing
    * fix: clear on add address button
2022-11-11 docs: components (#14)
    * docs: Maxim PUF
    * docs: more info on chips with PUF
    * docs: few more chips with PUF
    * docs: MCUs with PUF, dev boards
2022-11-11 feat: interface to add derivation (#17)
    * refactor: extract screens and utils
    * fix: data ownership
    * feat: derivation, network selector
    * feat: selector and uniffi
    * fix: change to explicit action constructor
    * feat: show all networks to select in new adderss screen
    * fix: compose network cards
    * feat: specs set export, use key set in derivations (#3)
    * feat: transmit address
    * style: some branding for Siltti
    * feat: prepare to show transmitted data parameters
    * feat: display available meta version (#4)
    * build: freeze parser commit
    * build: lock cargo
    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
    [process_input.rs]
2023-01-23 feat: initial hardware development (#22)
    * chore: update gitignote
    * feat: coil and screen prototype pcb
    * docs: readme
    * docs: document schematics
    * feat: add mock case models
    * feat: casing design solution
    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
    [2.7_e-inc_touch_design_44x38coil.STEP, CoilDisp.kicad_pcb, CoilDisp.kicad_sch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]
2023-03-26 major: first device prototype (#24)
    * feat: initial routing
    * feat: pcb labels
    * feat: update C1 version; add D version and tag
    [Coil_3T.kicad_pcb, Coil_3T.kicad_sch, Coil_4T.kicad_pcb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]
2023-03-26 feat: graphics prototyping (#32)
    * feat: ui simulator init
    * refactor: extract pincode mod
    * feat: pin code counter
    * feat: lock screen
    * refactor: extract UI state
    * chore: some lint
    * feat: seed entry screen
    * fead: restore or generate?
    * refactor: move control buttons defs to display defs
    * chore: gitignore
    * feat: start adding ui to app
    * feat: align screen and draw it
    * feat: user input works
    * fix: more sane ui flow
    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
    [gpio_pins.rs, main.rs, psram.rs]
2023-03-26 feat: Mechanical stuff for milestone4 (#37)
    * feat: mechanical design of casing for D edition
    * feat: casing renders
    * docs: some photos
    [kampela_D1_frame.STEP]
2023-03-26 feat: D1 mechanical design (#39)
    * D1 iteration enclosure design proccess
    * D1 iteration hardware process
    * D1 iteration hardware process
    * Update README.md
    * Update README.md
    * D1 small fixes
    ---------
    [2.7_e-inc_touch_design_44x38coil.STEP, CoilDisp.kicad_pcb, CoilDisp.kicad_sch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]
2023-03-27 chore: duplicate files cleanup
    [kampela_D1_frame.STEP]
2023-03-30 refactor: kampela-system cleanup (#42)
    * refactor: finally separate init by systems
    * feat: add touch calibration matrix
    * chore: warn cleanup
    * chore: more cleanup
    * refactor: limit gpio operations to GPIO_S
    * chore: use cleanup
2023-03-31 feat: kolibri for screen calibration (#34)
    * feat: kolibri for screen calibration
    * feat: affine transform for calibration
    * feat: allow to decline bad points, no screen update if not needed
    * chore: move to use kampela-display-common
    * feat: calibration app, use refactored kampela
    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
2023-05-02 fix: NFC packets proper length constants (#44)
    * fix: NFC packet length proper constants
    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
    [process_input.rs]
2023-05-03 chore: update gradle and small stuff in Siltti (#45)
    * chore: update gradle and small stuff in Siltti
    * fix: update android deps to fix cache invalidation nonsense
    * fix: try to make nfc sender in Siltti work with current protocol edition
    * chore: ungitignore manifests
    * fix: stop camera from harming nfc; updates
    * fix: off-by-4 in packet size constants
2023-06-07 feat: firmware logic (#43)
    * feat: add clap to ui crate
    * chore: cleanup ui crate
    * refactor: extract platform-depending operations from ui
    * feat: use mutex lock token in UI objects
    * feat: make peripherals access external to platform trait
    * fix: make both ui model and app work
    * feat: move display framebuffer into hardware trait
    * feat: 4-hex-digit pin
    * feat: ui shows seed backup and asks to repeat pin
    * feat: port onboarding to hardware
    * feat: replace visible_delay with delay
    * feat: hide peripherals in mutex
    * refactor: remove timer1
    * feat: functional parallel nfc listener (#5)
    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
    [gpio_pins.rs, main.rs]
2023-06-08 fix: correct address shift (#51)
    * fix: correct address shift
    * chore: remove some of dead code
    * chore: some cleanup
    [main.rs, nfc.rs]
2023-06-13 feat: freeze app in portrait, show frame count sometimes (#52)
    * feat: freeze app in portrait, show frame count sometimes
    * feat: counter reset button
2023-06-19 major: port system crate to E hardware edition (#53)
    * feat: E1 schematics
    * chore: backup C1 kampela-system version
    * feat: change pin locations
    * feat: UI works on E
    [Kampela.kicad_sch, Kampela_E1.kicad_pcb, Kampela_E1.kicad_sch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]
2023-06-24 feat: add dummy sender to siltti (#56)
    * feat: add dummy sender to siltti
    * fix: shutdown camera
2023-06-24 feat: send shortened metadata instead (#57)
    * feat: send shortened metadata instead
    * chore: bump app lockfile
    * fix: change meta payload code
    * fix: firmware fixes
    * chore: reconcile branches
    * fix: finally transmit transaction
    * feat: transaction maybe
    * feat: transaction parsing
    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
    [main.rs, nfc.rs, process_input.rs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]
2023-06-25 feat: draw qr codes; atm qrcodegen in no-heap mode locally (#54)
    * feat: draw qr codes; atm qrcodegen in no-heap mode locally
    * fix: patched qrcodegen repo
    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
    [main.rs]
2023-06-25 feat: receive payload and render in ui abstraction (#58)
    * feat: transaction preview screen stubs
    * feat: transaction preview builds in metal
    * fix: request update on transaction reception
    [main.rs]
2023-08-10 feat: this was able to sign a transaction on-chain (#60)
    * feat: this was able to sign a transaction on-chain
    * refactor: cleanup
    * feat: make red light shine
2023-08-29 chore: Siltti dependencies bump and older android support (#65)
    * chore: add support down to sdk 25 (7.1.1)
    * chore: bump android dependencies
    * feat: use java thread for nfc
    * feat: move to kotlin threading, live frame counter
2023-08-30 feat: implement metadata shortener (#66)
    * feat: implement metadata shortener
    * fix: revert ID_METADATA
    * fix: reverted properly to accept regular metadata QRs
    [main.rs, process_input.rs, psram.rs]
